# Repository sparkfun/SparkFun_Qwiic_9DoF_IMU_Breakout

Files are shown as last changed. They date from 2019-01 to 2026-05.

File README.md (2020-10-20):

SparkFun Qwiic 9DoF IMU  Breakout
========================================

SparkFun Qwiic 9DoF IMU Breakout

[*SparkFun Qwiic 9DoF IMU  Breakout (15335)*](https://www.sparkfun.com/products/15335)

The SparkFun 9DoF IMU Breakout incorporates all the amazing features of Invensense's ICM-20948 into a Qwiic-enabled breakout board complete with a logic shifter and broken out GPIO pins for all your motion sensing needs. The ICM-20948 itself is an extremely low powered, I2C and SPI enabled 9-axis motion tracking device that is ideally suited for smartphones, tablets, wearable sensors, and IoT applications. Utilizing our handy Qwiic system, no soldering is required to connect it to the rest of your system. However, we still have broken out 0.1"-spaced pins in case you prefer to use a breadboard.

In addition to the 3-Axis Gyroscope with four selectable ranges, 3-Axis Accelerometer, again with four selectable ranges, and 3-axis magnetometer with an FSR to ±4900µT, the ICM-20948 also includes a Digital Motion Processor that offloads the computation of motion sensing algorithms from the detectors, allowing optimal performance of the sensors. We've also broken out all the ICM-20948 pin functionality to GPIO and labeled them I2C on the front, SPI on the back for ease of identification.

Repository Contents
-------------------

* **/Documentation** - Data sheets, additional product information
* **/Hardware** - Eagle design files (.brd, .sch)
* **/Production** - Production panel files (.brd)

Documentation
--------------
* **[Arduino Library](https://github.com/sparkfun/SparkFun_ICM-20948_ArduinoLibrary)** - Arduino library for the SparkFun Qwiic 9DoF IMU  Breakout.
* **[Python Package](https://github.com/sparkfun/Qwiic_9DoF_IMU_ICM20948_Py)** - Python Package (Qwiic_Py) for the SparkFun Qwiic 9DoF IMU  Breakout.
* **[Hookup Guide](https://learn.sparkfun.com/tutorials/sparkfun-9dof-imu-icm-20948-breakout-hookup-guide)** - Basic hookup guide for the SparkFun 9DoF IMU Breakout.
* **[SparkFun Fritzing repo](https://github.com/sparkfun/Fritzing_Parts)** - Fritzing diagrams for SparkFun products.

License Information
-------------------

This product is _**open source**_! 

Please review the LICENSE.md file for license information. 

If you have any questions or concerns on licensing, please contact techsupport@sparkfun.com.

Distributed as-is; no warranty is given.

- Your friends at SparkFun.

_<COLLABORATION CREDIT>_

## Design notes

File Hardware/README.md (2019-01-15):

SparkFun <PRODUCT NAME> Design Files
=====================================

The .sch and .brd files hare are Eagle CAD schematic and PCB design files from SparkFun Electronics.
A freeware version of Eagle can be found [here](http://www.cadsoftusa.com/download-eagle/freeware/).

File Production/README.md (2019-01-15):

SparkFun <PRODUCT NAME> Production Files
=========================================

These are the production files SparkFun uses for printing PCBs.

License Information
-------------------
This product is open source! 

The hardware is released under [Creative Commons ShareAlike 4.0 International](https://creativecommons.org/licenses/by-sa/4.0/).

Please use, reuse, and modify these files as you see fit. Please maintain attribution to SparkFun Electronics and release anything derivative under the same license.

Distributed as-is; no warranty is given.

- Your friends at SparkFun.

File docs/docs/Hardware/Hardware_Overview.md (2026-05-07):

# Hardware Overview

We've put a lot of effort into making this the most useful and versatile breakout for the ICM 20948. Let's take a closer look at all the special parts.

### Sensor

At the heart of the board (metaphorically and geometrically) is the ICM 20948 from Invensense. This puppy packs the ability to measure up to 10 unique values (3 axes of acceleration, rotational rate, and magnetic strength data as well as an on-board temperature sensor). The sensor is placed dead-center between the four 4-40 stand-off mounting holes to drastically simplify computation in dynamics. 

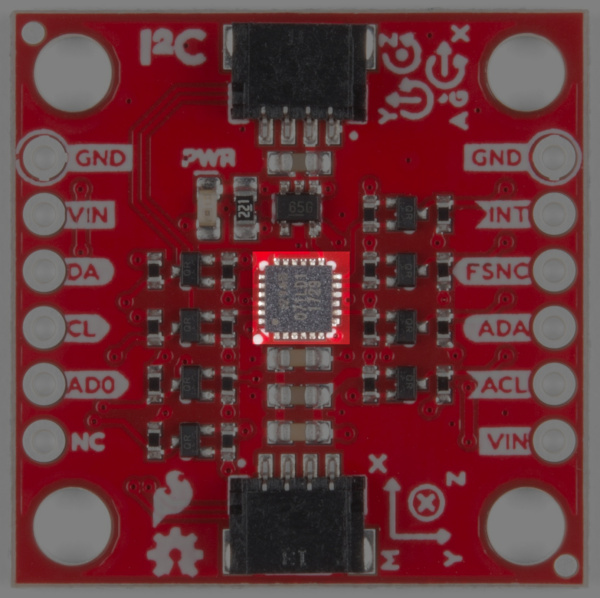
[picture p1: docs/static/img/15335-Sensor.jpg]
ICM20948 Sensor
[]

### Level Shifters

The ICM is a fickle fellow - optionally allowing a <b>3.3V</b> supply voltage but requiring I/O to work at 1.8V. This is just the price we pay for amazing technolojay (hey that rhymes). Since there aren't many popular development boards that run at the [voltage of the future](https://en.wikipedia.org/wiki/LVCMOS) we've added high speed level shifting to each and every IO pin. These cool MOSFETS allow for bi-directional voltage translation up to the maximum SPI speed of the ICM - 7MHz - which will allow you to make inertial measurements with fantastic temporal resolution. Feel free to use the ICM IO anywhere from 1.8V to 5.5V!

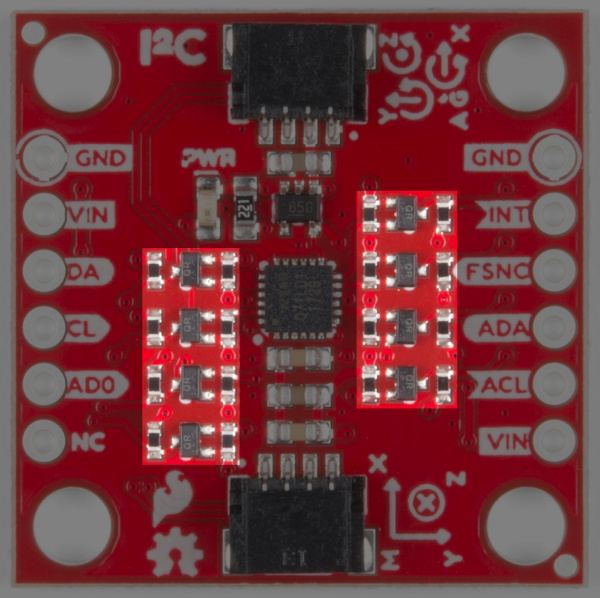
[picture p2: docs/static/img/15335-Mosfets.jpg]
Mosfets
[]

### Power

Input power on this board should be between **1.8-5.5V**. The ICM is riding the wave of 1.8V level devices so we've included a built-in regulator to make it easy to interface with 3.3V or 5V microcontrollers. There is an LED on the front of the board that will light up when the board is powered correctly. You can disable the LED functionality by cutting the LED jumper on the back of the board. This is described in the **_Jumpers_** section below. 

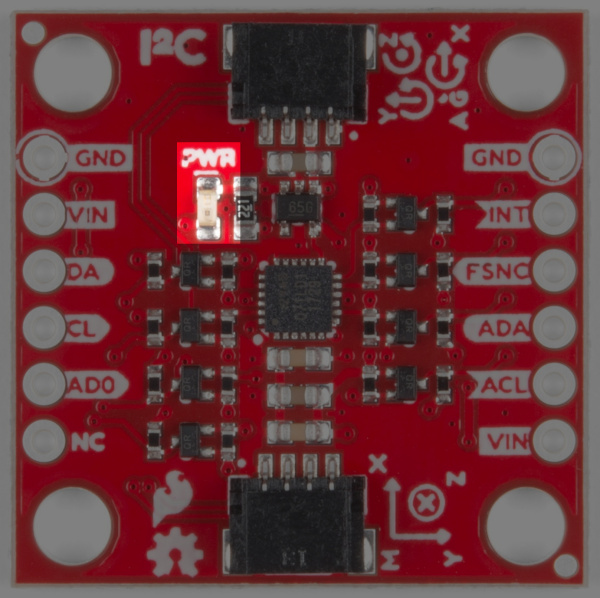
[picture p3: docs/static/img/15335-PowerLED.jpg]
Power LED
[]

### Qwiic Connectors

There are two Qwiic connectors on the board such that you can daisy-chain the boards should you choose to do so. If you're unfamiliar with our Qwiic system, head on over to our [Qwiic page](https://www.sparkfun.com/qwiic) to see the advantages! Of course, if you don't want to use Qwiic we've still broken out every pin on 0.1" spaced plated through-hole headers. You can find more information about these connections in the **_Headers_** section.

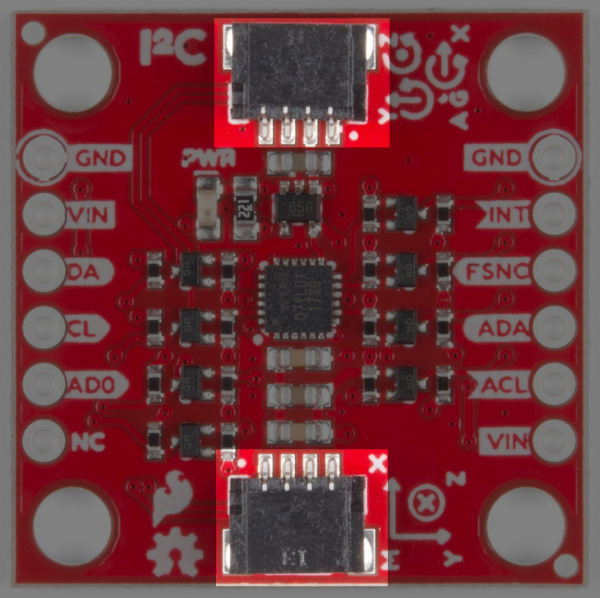
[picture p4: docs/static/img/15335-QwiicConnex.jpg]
Qwiic Connectors
[]

### GPIO

For flexibility, we've broken out functional pins for both I<sup>2</sup>C and SPI. There are no modifications required to switch between I<sup>2</sup>C mode and SPI out of the box, but if the 'ADR' jumper on the back is closed SPI will be unavailable.

| | |
| --- | --- |
| (https://cdn.sparkfun.com/r/600-600/assets/learn_tutorials/8/9/3/15335-GPIO_I2C.jpg) | (https://cdn.sparkfun.com/r/600-600/assets/learn_tutorials/8/9/3/15335-GPIO_SPI.jpg) |
| _I2C Pin Labels_ | _SPI Pin Labels_ |

### Jumpers

Look at all those jumpers on the back of the board! Here's what they do:  

#### Pullup Jumpers

* **I<sup>2</sup>C Pullup** - Does nothing, the pullups are not populated on the board because the TXS0108 has them built-in
* **Aux Pullup** - Cut these jumpers to disconnect the pullup resistors from the auxiliary I<sup>2</sup>C bus  

#### LED Jumper

* Cutting this jumper allows you to disable the LED functionality on the front of the board. 

#### Address Jumper

* When open (default) the address of the ICM is 0x69 and it is possible to use SPI communication. When soldered closed the address changes to 0x68. Closing the jumper prevents you from using SPI.

| | | |
| --- | --- | --- |
| (https://cdn.sparkfun.com/r/600-600/assets/learn_tutorials/8/9/3/15335-PullupJumpers.jpg) | (https://cdn.sparkfun.com/r/600-600/assets/learn_tutorials/8/9/3/15335-LEDJumper.jpg) | (https://cdn.sparkfun.com/r/600-600/assets/learn_tutorials/8/9/3/15335-AddrJumper.jpg) |
| _Pullup Jumpers_ | _LED Jumper_ | _I2C Address Jumper_ |

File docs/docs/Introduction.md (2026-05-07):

The [SparkFun 9DoF IMU Breakout](https://www.sparkfun.com/products/15335) incorporates all the amazing features of Invensense's ICM-20948 into a Qwiic-enabled breakout board replete with logic shifting and broken out GPIO pins for all your motion sensing needs. The ICM-20948 itself is an extremely low powered, I<sup>2</sup>C and SPI enabled 9-axis motion tracking device that is ideally suited for smartphones, tablets, wearable sensors, and IoT applications. Featuring a 3-Axis Gyroscope with four selectable ranges, a 3-Axis Accelerometer, again with four selectable ranges, a 3-axis compass with a wide range to  ±4900 µT, and an on-board Digital Motion Processor, this little breakout can even detect the motion of invisibility cloaks. Not really. Just checking to see if you were still with me. But it _is_ pretty amazing.

In this hookup guide, we'll connect our sensor up to our [Esp32 Thing Plus](https://www.sparkfun.com/products/14689) microcontroller and run a of quick (Qwiic) example to get you up and running with this fantastic board! 

### Required Materials

To follow along with this tutorial, you will need the 9DoF IMU Breakout with the following materials:

* [SparkFun Thing Plus - ESP32 WROOM](https://www.sparkfun.com/sparkfun-thing-plus-esp32-wroom-micro-b.html)
* [Qwiic Cable](https://www.sparkfun.com/flexible-qwiic-cable-100mm.html)
* [USB Micro-B Cable](https://www.sparkfun.com/reversible-usb-a-to-reversible-micro-b-cable-0-3m.html)

### Tools

If you choose to utilize the broken out GPIO, you will need a soldering iron, solder, and [general soldering accessories](https://www.sparkfun.com/categories/49).

* [Soldering Iron - 60W (Adjustable Temperature)](https://www.sparkfun.com/soldering-iron-60w-adjustable-temperature.html)
* [Solder Lead Free - 15-gram Tube](https://www.sparkfun.com/solder-lead-free-15-gram-tube.html)

### Suggested Reading

If you aren't familiar with the Qwiic system, we recommend reading [here for an overview](https://www.sparkfun.com/qwiic).

We would also recommend taking a look at the following tutorials if you aren't familiar with them:

* [How to Solder: Through-Hole Soldering](https://learn.sparkfun.com/tutorials/how-to-solder-through-hole-soldering)
* [Accelerometer Basics](https://learn.sparkfun.com/tutorials/accelerometer-basics)
* [I2C](https://learn.sparkfun.com/tutorials/i2c)
* [Serial Terminal Basics](https://learn.sparkfun.com/tutorials/terminal-basics)

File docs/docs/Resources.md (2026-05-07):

For more information on the ICM-20948, check out the links below: 

* [Schematic (PDF)](https://cdn.sparkfun.com/assets/c/7/8/f/8/15335_9DoF_Schematic.pdf)
* [Eagle Files(ZIP)](https://cdn.sparkfun.com/assets/e/3/8/8/4/15335_9DoF_IMU_EagleFiles.zip)
* [ICM-20948 Datasheet](https://cdn.sparkfun.com/assets/learn_tutorials/8/9/3/DS-000189-ICM-20948-v1.3.pdf)
* [ICM-20948 Arduino Library GitHub](https://github.com/sparkfun/SparkFun_ICM-20948_ArduinoLibrary)
* [Qwiic_9DoF_IMU_ICM20948_Py Python Module](https://github.com/sparkfun/Qwiic_9DoF_IMU_ICM20948_Py)
    * [ReadTheDocs](https://qwiic-9dof-imu-icm20948-py.readthedocs.io/en/latest/?)
* [9DoF IMU GitHub](https://github.com/sparkfun/SparkFun_Qwiic_9DoF_IMU_Breakout)

This tutorial focuses on using the 9DoF with Arduino. To use the ICM-20948 on a Raspberry Pi with Python, check out the [Qwiic SHIM Kit Hookup Guide for Raspberry Pi](https://learn.sparkfun.com/tutorials/qwiic-shim-kit-hookup-guide-for-raspberry-pi) for more information.

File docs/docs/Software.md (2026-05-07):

In this example, we are using the [SparkFun Esp32 Thing WROOM Plus](https://www.sparkfun.com/products/14689). If you have not used this board before, head on over to the [ESP32 Thing Plus Hookup Guide](https://learn.sparkfun.com/tutorials/esp32-thing-plus-hookup-guide) for a general overview, as well as information on getting set up with board definitions.

In order to use the ICM-20948 breakout, you'll need to install the [SparkFun ICM-20948 Arduino Library](https://github.com/sparkfun/SparkFun_ICM-20948_ArduinoLibrary).  We recommend you install the library via the Arduino IDE by using the library manager and search for **Sparkfun 9DoF IMU Breakout**. Users who want to manually install the library can download it from the the [GitHub repo](https://github.com/sparkfun/SparkFun_ICM-20948_ArduinoLibrary).

### Example 1

In this example, we've hookup up our ICM-20948 to an [ESP32 Thing Plus](https://www.sparkfun.com/products/14689) using a short [Qwiic cable](https://www.sparkfun.com/products/14427). 

Once you've installed the ICM-20948 library, load the first example sketch from **File**->**Examples**->**SparkFun 9DoF IMU Breakout - ICM 20948 - Arduino Library**->**Arduino**->**Example1_Basics**. 

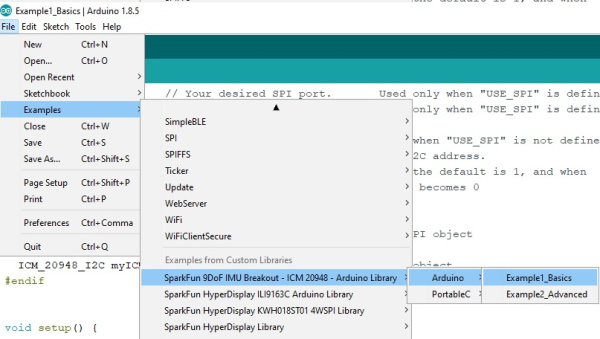
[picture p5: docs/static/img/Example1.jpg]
Where to find Example 1 in Arduino
[]

The very first thing you'll see in the code is the `#include` statement for the library. Alongside that is a convenient link that will help you get the library through the Arduino library manager. Next is a commented out `#define` statement called 'USE_SPI'. If instead you have chosen to connect your ICM with the SPI pins all you need to do is uncomment that line.

``` c
    #include "ICM_20948.h"  // Click here to get the library: http://librarymanager/All#SparkFun_ICM_20948_IMU
    
    //#define USE_SPI       // Uncomment this to use SPI
```    

Up next is a short section where you can configure your particular setup. First of all if you need to change your serial port, e.g. if you're using a SAMD21 board, you can change the 'SERIAL_PORT' define ('SerialUSB' for SAMD21). You can do the same to change your I2C port or SPI port, depending on which you're using. When using I2C you have the ability to change the I2C address of the sensor with the Address 0 bit. By default it is '1' but you could change it to 0 if you've closed the 'ADR' jumper. When using SPI you need to specify a chip select pin - in the example we default to pin 2.

``` c
    #define SERIAL_PORT Serial
    
    #define SPI_PORT SPI    // Your desired SPI port.       Used only when "USE_SPI" is defined
    #define CS_PIN 2        // Which pin you connect CS to. Used only when "USE_SPI" is defined
    
    #define WIRE_PORT Wire  // Your desired Wire port.      Used when "USE_SPI" is not defined
    #define AD0_VAL   1     // The value of the last bit of the I2C address. 
                            // On the SparkFun 9DoF IMU breakout the default is 1, and when 
                            // the ADR jumper is closed the value becomes 0
```

That's it for stuff you (might) need to do to set up the example! Now we'll just all hop in the bus, take a tour, and I'll point out items on your right and left.

The next little block creates either a `ICM_20948_I2C` or `ICM_20948_SPI` object called 'myICM'. Since they have the same name, and they both inherit from the grandaddy `ICM_20948` class, we'll be able to use them interchangeably later on in the example.

``` c
    #ifdef USE_SPI
      ICM_20948_SPI myICM;  // If using SPI create an ICM_20948_SPI object
    #else
      ICM_20948_I2C myICM;  // Otherwise create an ICM_20948_I2C object
    #endif
```

In the `setup()` function we have your standard Arduino initialization of your serial port, and then we have the last interface-dependent section. There you'll see the 'myICM' object being started up with the appropriate arguments for the chosen interface. This example shows all arguments being explicitly stated, but it is also possible to call the `.begin()` function with default arguments. The initialization will repeat with a delay until the device is successfully found. If it is not connecting try checking your wiring.

``` c
    #ifdef USE_SPI
        SPI_PORT.begin();
        myICM.begin( CS_PIN, SPI_PORT ); 
    #else
        WIRE_PORT.begin();
        WIRE_PORT.setClock(400000);
        myICM.begin( WIRE_PORT, AD0_VAL );
    #endif
```

Here's a little trick for debugging the ICM - nearly all operations will update the internal 'myICM.status' value. You can check it directly (0 means all good, anything else is an error) or you can use the `statusString()` method to get the latest status in human-readable form.

``` c
        SERIAL_PORT.print( F("Initialization of the sensor returned: ") );
        SERIAL_PORT.println( myICM.statusString() );
        if( myICM.status != ICM_20948_Stat_Ok ){
          SERIAL_PORT.println( "Trying again..." );
          delay(500);
        }else{
          initialized = true;
        }
```

The last part of the sketch is the `loop()` where the sensor gets polled for new data, and that data gets pushed over the serial port. All the data is contained in the 'AGMT' structure, which stands for Accelerometer, Gyroscope, Magnetometer, and Temperature sensors. For convenience this sketch also includes functions (that are not part of the library) to print the results in a pretty format. 

``` c
    void loop() {
    
      if( myICM.dataReady() ){
        myICM.getAGMT();                // The values are only updated when you call 'getAGMT'
    //    printRawAGMT( myICM.agmt );     // Uncomment this to see the raw values, taken directly from the agmt structure
        printScaledAGMT( myICM.agmt);   // This function takes into account the sclae settings from when the measurement was made to calculate the values with units
        delay(30);
      }else{
        Serial.println("Waiting for data");
        delay(500);
      }
      
    }
```
    
When you open up your [Serial Monitor](https://learn.sparkfun.com/tutorials/terminal-basics), you should see something like the following: 

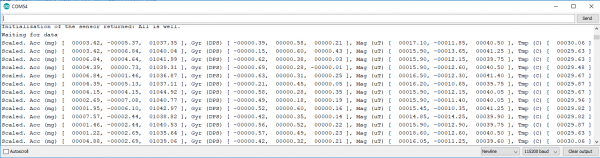
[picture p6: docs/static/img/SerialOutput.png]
Serial Output
[]

There ya have it! Now go ahead and hack it up.

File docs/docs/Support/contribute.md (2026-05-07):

# Contribute

## Improve our Documentation

All of this documentation can be modified by you! Please help us make it better.

* These pages are contained in the [`docs` folder of the SparkFun Qwiic 9DoF IMU Breakout repository](https://github.com/sparkfun/SparkFun_Qwiic_9DoF_IMU_Breakout/tree/main/docs).

### Submit a Correction

1. Fork this repo
2. Add your corrections or improvements to the markdown file
3. File a pull request with your changes, and enjoy making the ~~words~~ ~~worlds~~ world a better place.
    * Once received, the documentation specialist will automatically be notified.
    * We will review your suggested improvements to make sure they are correct and fit within our documentation standards.

## Improve our Hardware Design

This hardware design is open-source! Please help us make it better.

* Our board design files are contained in the [`Hardware` folder of the SparkFun Qwiic 9DoF IMU Breakout repository](https://github.com/sparkfun/SparkFun_Qwiic_9DoF_IMU_Breakout_IoT_9DoF/tree/main/Hardware).

### Submit a Design Improvement

1. Fork this repo
2. Add your design improvements
3. File a pull request with your changes, and enjoy making the ~~words~~ ~~worlds~~ world a better place.
    * Once received, the engineer in charge of the original design will automatically be notified.
    * We will review your suggested improvements, if they are within our board design standards and meet our product design requirements, we will flag these changes for our next board revision. *(Please note, that even if your suggestion is accepted, these changes may not be immediate. We may have to cycle through our current product inventory first.)*

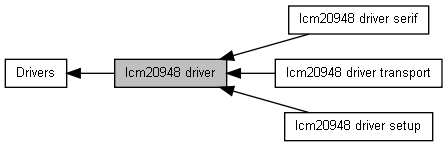
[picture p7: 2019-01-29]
Documentation/eMD/1.0.0/doc/libIDD/html/a00122.png

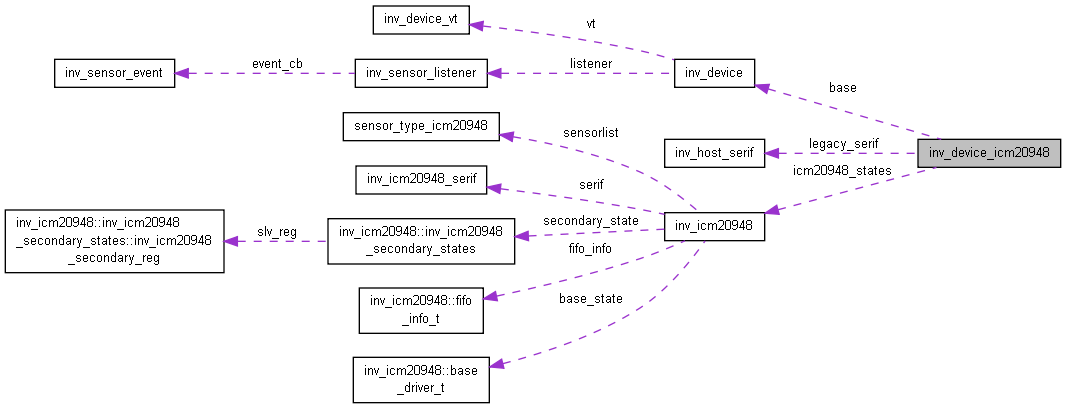
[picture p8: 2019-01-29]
Documentation/eMD/1.0.0/doc/libIDD/html/a00148.png

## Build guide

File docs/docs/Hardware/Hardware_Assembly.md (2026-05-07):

# Hardware Assembly

One of the many advantages of the Qwiic system is that hooking up your hardware is extremely simple. Simply grab a Qwiic cable and plug your 9DoF in! 

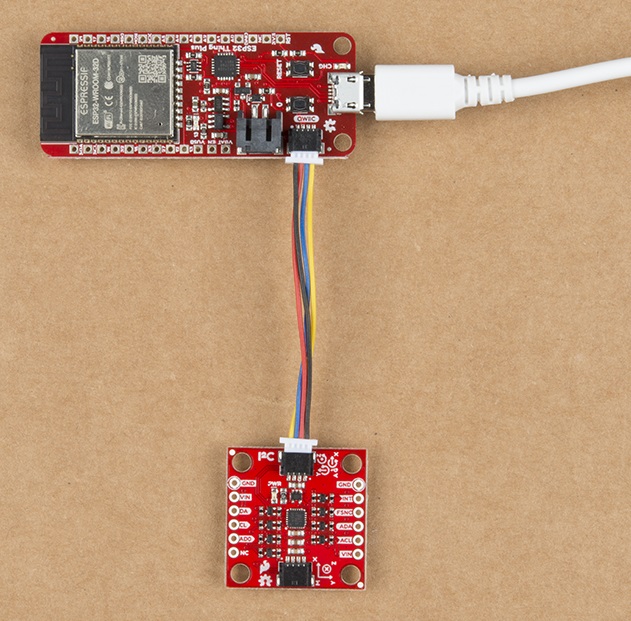
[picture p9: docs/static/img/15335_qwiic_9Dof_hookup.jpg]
Connecting the 9DoF Breakout to a microcontroller via Qwiic cable
[]

<div class="alert alert-danger" role="alert"><b>&#x26A1;WARNING!</b> <br />If you are using the ESP32 Thing Plus, make sure your power supply is <b>5V</b>, NOT 5.1V. We have noticed a power spike in our <a href="https://www.sparkfun.com/products/13831"> 5.1V power supplies</a>, that can damage the IC on the ESP32 Thing Plus. Long cables can also generate a large enough voltage spike to damage the IC. We recommend keeping power supply cables shorter than 6 feet to minimize potential damage.</div>

If you'd like to use the broken out GPIO pins, things get a bit more complicated. That said, to make life a little easier we've organized them by function, and provided lots of labels. You'll first notice that one side has the text 'I<sup>2</sup>C' and the other side says 'SPI.' The labels on either side are those that apply to that kind of communication. 

| | |
| --- | --- |
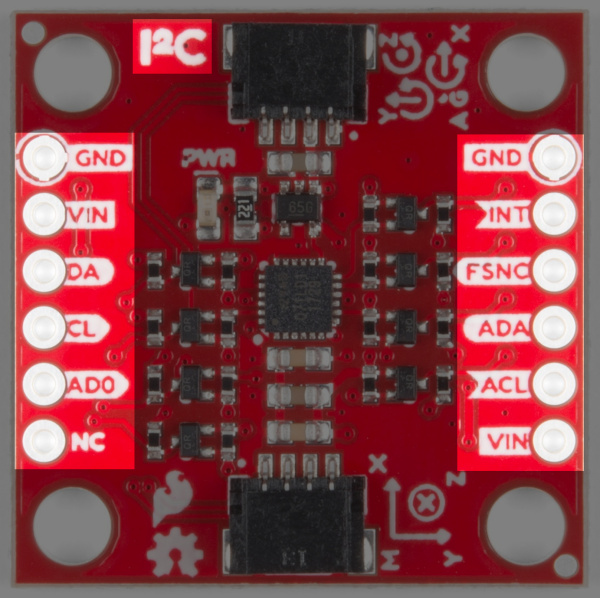
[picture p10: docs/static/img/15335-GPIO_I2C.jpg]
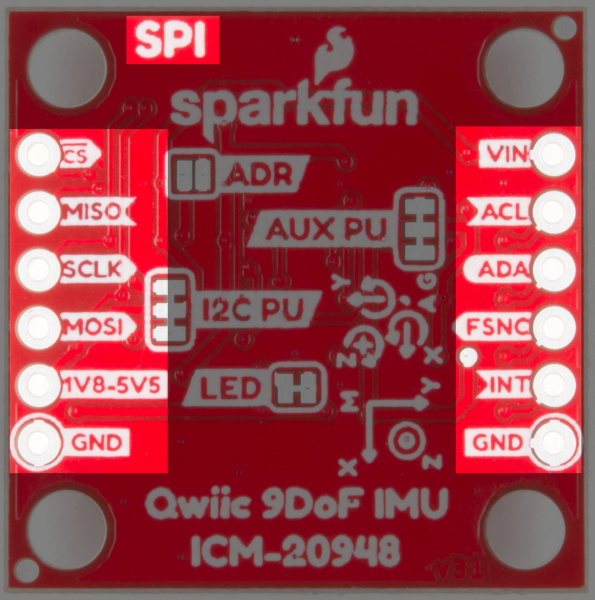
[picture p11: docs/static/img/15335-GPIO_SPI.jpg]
|  |  |
| _I2C Pin Labels_ | _SPI Pin Labels_ |

Next, you'll see that on the left side are the main connections to the host microcontroller. When connecting I<sup>2</sup>C you'll have a 'No Connect' pin that serves as the chip select when using SPI. As noted before, there are no modifications required to switch between I<sup>2</sup>C mode and SPI out of the box. However if the 'ADR' jumper is closed SPI will be unavailable.

On the right side are connections to external sensors that can be controlled by the ICM, as well as the 'INT' and 'FSYNC' interrupt pins. The auxiliary I<sup>2</sup>C bus pins are level shifted to/from the 'VIN' level that you supply. 

| Breakout Board Pin Functions (SPI) | | | |
| --- | --- | --- | --- |
| Breakout Pin | Arduino Uno | Esp32 Thing Plus | Microcontroller Pin Requirements |
| MOSI | 11  | 18  | Data output of chosen SPI port |
| SCLK | 13  | 5 | Clock output of chosen SPI port |
| MISO | 12  | 19  | Data input of chosen SPI port |
| CS  | 2 | 2 | An output pin to select the ICM for SPI |

| Breakout Board Pin Functions (I2C) | | | |
| --- | --- | --- | --- |
| Breakout Pin | Arduino Uno | Esp32 Thing Plus | Microcontroller Pin Requirements |
| DA  | SDA | 23  | Data line of chosen I2C port |
| CL  | SCL | 22  | Clock line of chosen I2C port |
| AD0 | \-  | \-  | Optional - use to control I2C address from software |

| Breakout Board Pin Functions (Auxiliary I2C and Interrupts) | | | |
| --- | --- | --- | --- |
| Breakout Pin | Arduino Uno | Esp32 Thing Plus | Microcontroller Pin Requirements |
| ADA | \-  | \-  | Data line of auxiliary I2C bus |
| ACL | \-  | \-  | Clock line of auxiliary I2C bus |
| FSYNC | \-  | \-  | Optional - synchronize measurements with a signal out from the microcontroller |
| INT | \-  | \-  | Optional - respond to configurable interrupts in from the ICM |

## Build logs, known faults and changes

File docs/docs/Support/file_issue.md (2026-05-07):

# Submit Issues

## Support

If you need technical assistance and more information on a product that is not working as you expected, visit the [SparkFun Community](https://community.sparkfun.com). The community forums are monitored by the SparkFun Technical Support Team and the SparkFun community as a whole.

## Existing Issue

Spot something wrong? Please check the list of reported and fixed issues  .  in this repository.

## Discrepancies in the Documentation

All of this documentation can be modified by you! Please help us make it better.

* The documentation files for these pages are contained in the [`docs` folder of the SparkFun Qwiic 9DoF IMU Breakout repository](https://github.com/sparkfun/SparkFun_Qwiic_9DoF_IMU_Breakout/tree/main/docs).

### Spot something wrong?

If a section of the documentation is incorrect, please [open an issue](https://github.com/sparkfun/SparkFun_Qwiic_9DoF_IMU_Breakout/issues) and let us know.

### Do you have a suggested correction?

1. With a GitHub account, fork this repo
2. Add your correction(s) or improvement(s) to the markdown file(s)
3. File a pull request with your changes, and enjoy making the ~~words~~ ~~worlds~~ world a better place.
    * Once received, the documentation specialist will automatically be notified.
    * We will review your suggested improvement(s) to make sure they are correct and fit within our documentation standards.

## Problems in the Hardware Design

All of our designs are open-source! Please help us make it better.

* Our board design files are contained in the [`Hardware` folder of the SparkFun Qwiic 9DoF IMU Breakout repository](https://github.com/sparkfun/SparkFun_Qwiic_9DoF_IMU_Breakout/tree/main/Hardware).

### Does something not make sense?

If part of the design is confusing, please [open an issue](https://github.com/sparkfun/SparkFun_Qwiic_9DoF_IMU_Breakout/issues) and let us know.

### Did we forget to include an important function of the board?

Please keep in mind that we may intentionally exclude certain functions of the board to meet our product design requirements.

If part of the board's functionality is missing, please [open an issue](https://github.com/sparkfun/SparkFun_Qwiic_9DoF_IMU_Breakout/issues) and file a feature request.

### Do you wish to contribute directly to improving the board design?

1. With a GitHub account, Fork this repo
2. Add your design improvement(s)
3. File a pull request with your changes, and enjoy making the ~~words~~ ~~worlds~~ world a better place.
    * Once received, the engineer in charge of the original design will automatically be notified.
    * We will review your suggested improvement(s), if they are within our board design standards and meet our product design requirements, we will flag these changes for our next board revision. *(Please note, that even if your suggestion is accepted, these changes may not be immediate. We may have to cycle through our current product inventory first.)*

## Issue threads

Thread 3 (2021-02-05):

Level Shifting MOSFET and Power Regulator

iharshadec, 2021-02-05:
Looks Like my board is damaged as it's not generating Power.
What is the regulator and mosfet used in this design?

PaulZC, 2021-02-15:
Hi @iharshadec ,
Apologies for the delay. From the Eagle files: the regulator is a SP6214-1.8V; the FET is RE1C002UN.
Best wishes,
Paul

iharshadec, 2021-02-16:
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

Thank you Paul,
I will order this regulator first and replace to see if I get the board working back.

Closed 2021-02-15.

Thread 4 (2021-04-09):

Low-power mode: Extremely high power consumption

adamgarbo, 2021-04-09:
Hi folks,

I've been meaning to follow up on a GitHub issue I previously raised regarding the ICM-20948's high power consumption: (https://github.com/sparkfun/SparkFun_ICM-20948_ArduinoLibrary/issues/21). It appears that the level shifting circuitry on the ICM-20948 is causing an extremely high current draw of 3.4 mA when placed in low power mode that cannot be disabled.

When in Full-Chip Sleep Mode the ICM-20948 should be able to achieve a quiescent draw of 8 uA. As the ICM-20948 is now the "go-to" IMU, I believe it would be a worthwhile effort to address this power consumption issue when time permits.

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

Cheers,
Adam

adamgarbo, 2022-03-10:
Closing as unresolved. High power consumption is a known issue for the ICM-20948.

Closed 2022-03-10.

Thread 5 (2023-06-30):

How to get this sensor working on lineage OS?

anivader1789, 2023-06-30:
We have this IMU sensor and we have a rasberry pi 4 Model B. Installed Lineage OS on it (https://konstakang.com/devices/rpi4/LineageOS20/). We want to install drivers for this sensor to work with our setup. Any help appreciated.

PaulZC, 2023-07-01:
Hi @anivader1789 ,

Please see: https://github.com/sparkfun/Qwiic_9DoF_IMU_ICM20948_Py

Best wishes,
Paul

Closed 2023-07-01.

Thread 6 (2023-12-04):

Wrong values for accelerometer configuration

ezono-Muhammad, 2023-12-04:
### Subject of the issue
Wrong values for accelerometer configuration

### Your workbench
* Raspberry pi 4
* I2C. IMU address is 0x68
* Via i2c connection on Raspberry pi 4

### Steps to reproduce
Using the following code :

```
from __future__ import print_function
import qwiic_icm20948
import time
import sys

if __name__ == "__main__":

    IMU = qwiic_icm20948.QwiicIcm20948(address=0x68)
    IMU.setBank(2)
    IMU._i2c.writeByte(IMU.address, IMU.AGB2_REG_ACCEL_CONFIG_1, 0x23)
    register = IMU._i2c.readByte(IMU.address, IMU.AGB2_REG_ACCEL_CONFIG_1)
    print(register)
```

### Expected behaviour
The return value should be 0x23

### Actual behaviour
The return value is 0x01

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

Closed 2023-12-04.

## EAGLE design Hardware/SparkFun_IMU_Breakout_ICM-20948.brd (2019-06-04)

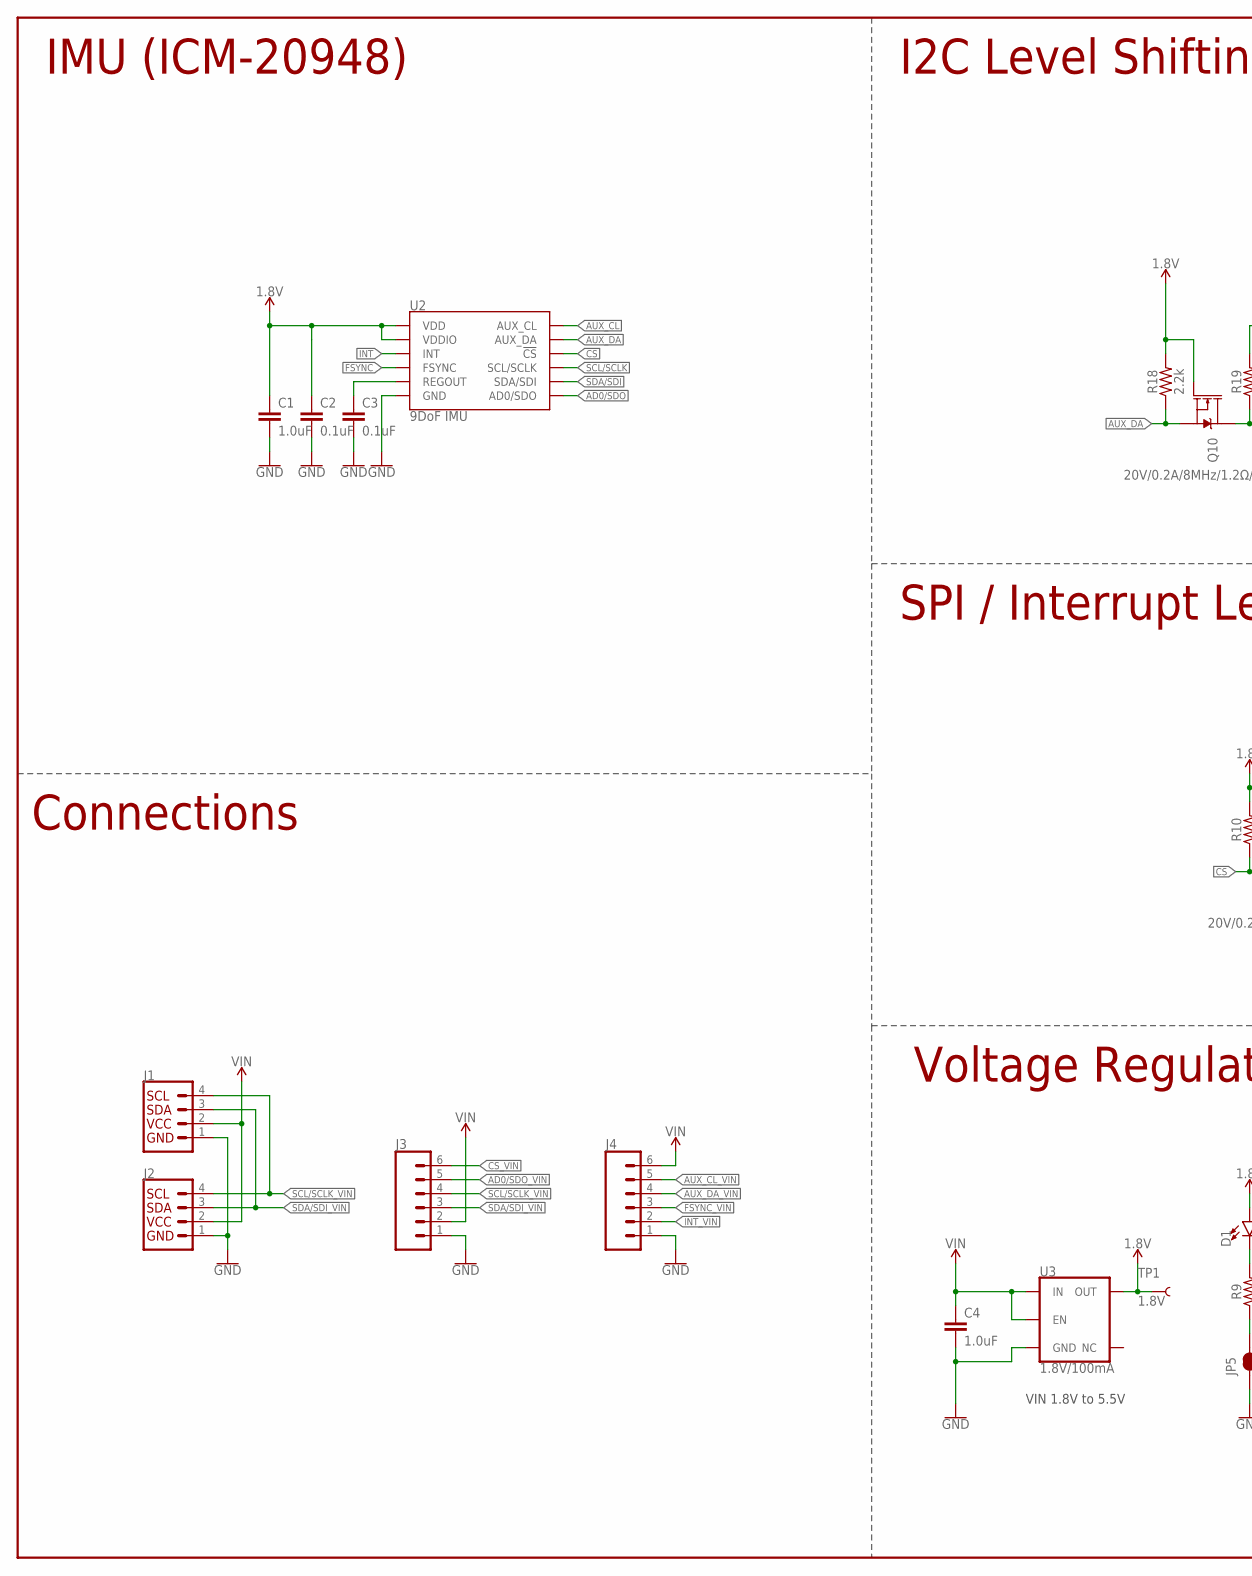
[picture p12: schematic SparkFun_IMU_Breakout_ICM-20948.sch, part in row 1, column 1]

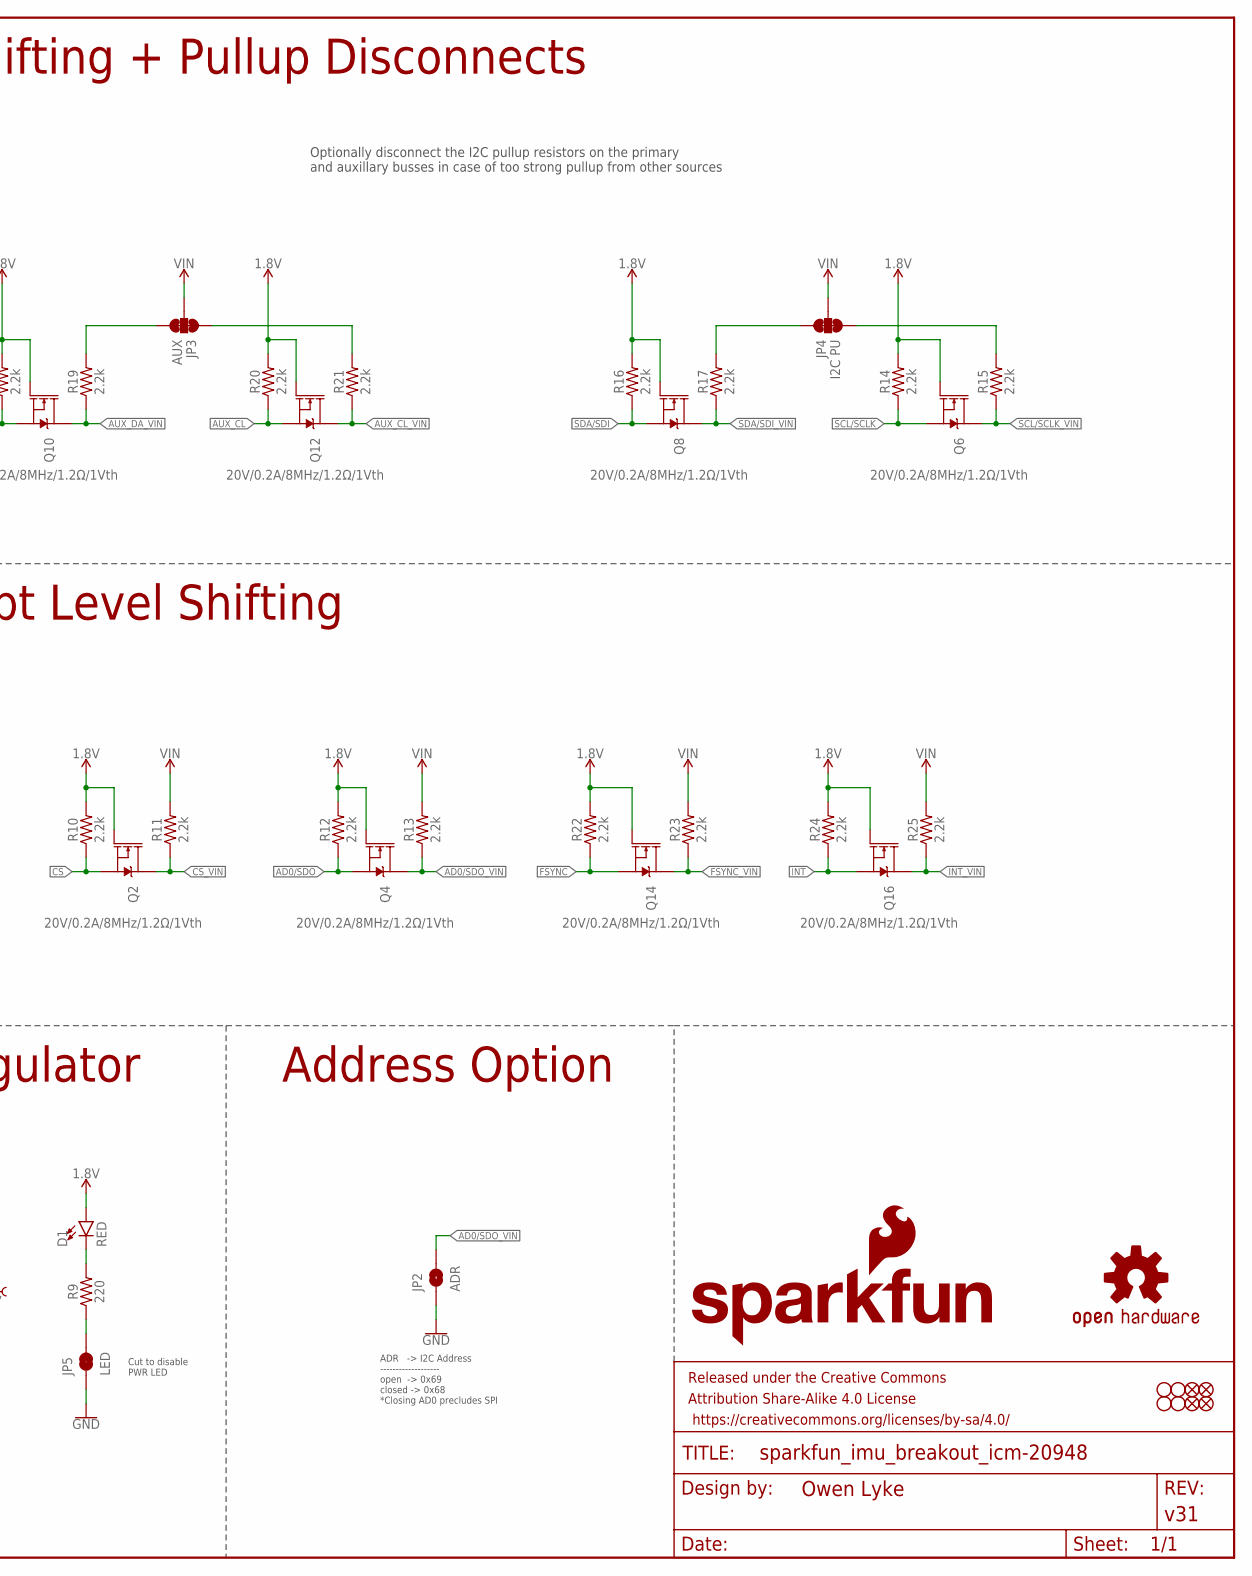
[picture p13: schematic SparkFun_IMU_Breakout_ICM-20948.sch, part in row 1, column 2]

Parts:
C1, C4: 1.0uF; 0603
C2, C3: 0.1uF; 0603
D1: RED; LED-0603
FD1, FD2, FD3, FD4: FIDUCIAL1X2; FIDUCIAL-1X2
FRAME2: FRAME-LEDGER; CREATIVE_COMMONS
H1, H2, H3, H4: STAND-OFF
J1, J2: QWIIC_CONNECTORJS-1MM; JST04_1MM_RA
J3, J4: CONN_06NO_SILK_NO_POP; 1X06_NO_SILK
JP2: ADR; SMT-JUMPER_2_NO_SILK
JP3: AUX; SMT-JUMPER_3_2-NC_TRACE_SILK
JP4: I2C PU; SMT-JUMPER_3_2-NC_TRACE_SILK
JP5: LED; SMT-JUMPER_2_NC_TRACE_SILK
LOGO1: SFE_LOGO_NAME_FLAME.1_INCH; SFE_LOGO_NAME_FLAME_.1
LOGO2: OSHW-LOGOMINI; OSHW-LOGO-MINI
Q2, Q4, Q6, Q8, Q10, Q12, Q14, Q16: 20V/0.2A/8MHz/1.2Ω/1Vth; SOT-416FL
R9: 220; 0603
R10, R11, R12, R13, R14, R15, R16, R17, R18, R19, R20, R21, R22, R23, R24, R25: 2.2k; 0402-TIGHT
TP1: 1.8V; PAD.03X.03
U2: 9DoF IMU; QFN24-3X3
U3: 1.8V/100mA; SC70

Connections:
1.8V: C1.1, C2.1, D1.A, Q2.1 (G), Q4.1 (G), Q6.1 (G), Q8.1 (G), Q10.1 (G), Q12.1 (G), Q14.1 (G), Q16.1 (G), R10.2, R12.2, R14.2, R16.2, R18.2, R20.2, R22.2, R24.2, TP1.P$1, U2.8 (VDDIO), U2.13 (VDD), U3.5 (OUT)
!CS: Q2.2 (S), R10.1, U2.22 (!CS)
!CS!_VIN: J3.6, Q2.3 (D), R11.1
AD0/SDO: Q4.2 (S), R12.1, U2.9 (AD0/SDO)
AD0/SDO_VIN: J3.5, JP2.2, Q4.3 (D), R13.1
AUX_CL: Q12.2 (S), R20.1, U2.7 (AUX_CL)
AUX_CL_VIN: J4.5, Q12.3 (D), R21.1
AUX_DA: Q10.2 (S), R18.1, U2.21 (AUX_DA)
AUX_DA_VIN: J4.4, Q10.3 (D), R19.1
FSYNC: Q14.2 (S), R22.1, U2.11 (FSYNC)
FSYNC_VIN: J4.3, Q14.3 (D), R23.1
GND: C1.2, C2.2, C3.2, C4.2, J1.1, J2.1, J3.1, J4.1, JP2.1, JP5.1, U2.18 (GND), U2.20 (GND), U3.2 (GND)
INT: Q16.2 (S), R24.1, U2.12 (INT)
INT_VIN: J4.2, Q16.3 (D), R25.1
unnamed: C3.1, U2.10 (REGOUT)
unnamed: JP4.3, R15.2
unnamed: JP4.1, R17.2
unnamed: JP3.1, R21.2
unnamed: JP3.3, R19.2
unnamed: D1.C, R9.2
unnamed: JP5.2, R9.1
SCL/SCLK: Q6.2 (S), R14.1, U2.23 (SCL/SCLK)
SCL/SCLK_VIN: J1.4, J2.4, J3.4, Q6.3 (D), R15.1
SDA/SDI: Q8.2 (S), R16.1, U2.24 (SDA/SDI)
SDA/SDI_VIN: J1.3, J2.3, J3.3, Q8.3 (D), R17.1
VIN: C4.1, J1.2, J2.2, J3.2, J4.6, JP3.2, JP4.2, R11.2, R13.2, R23.2, R25.2, U3.1 (IN), U3.3 (EN)

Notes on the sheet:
VIN 1.8V to 5.5V
IMU (ICM-20948)
I2C Level Shifting + Pullup Disconnects
Connections
Voltage Regulator
SPI / Interrupt Level Shifting
ADR -> I2C Address ------------------- open -> 0x69 closed -> 0x68 *Closing AD0 precludes SPI
Optionally disconnect the I2C pullup resistors on the primary and auxillary busses in case of too strong pullup from other sources
Cut to disable PWR LED
Address Option

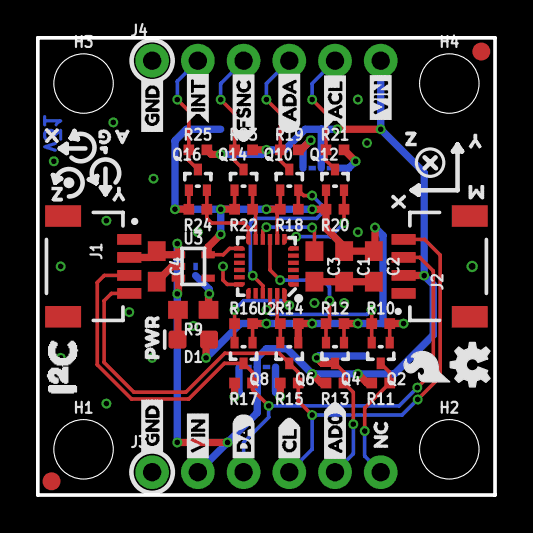
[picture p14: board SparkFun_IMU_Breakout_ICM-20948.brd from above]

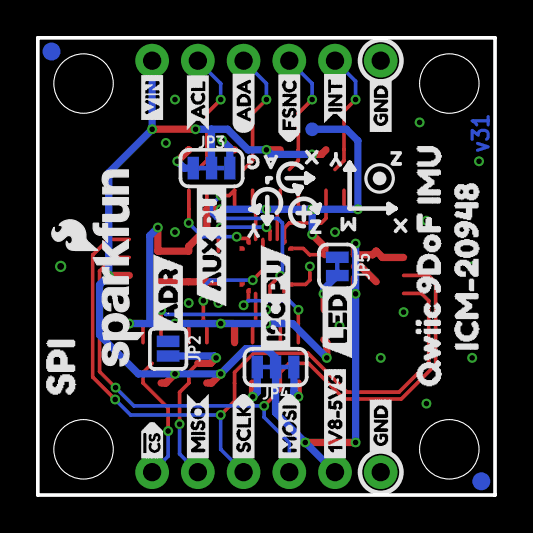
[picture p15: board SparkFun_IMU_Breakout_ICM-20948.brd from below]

Board: 2 copper layers, 25.4 x 25.4 mm, 104 parts (36 on the bottom side), 26 nets.

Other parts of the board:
U$1, U$2, U$22, U$24: GND4
U$3: PWR0
U$4, U$21: INT3
U$5, U$20: FSNC2
U$6, U$19: ACL1
U$7, U$18: ADA0
U$8: MISO13
U$9: MOSI14
U$10: SCLK15
U$11: #CS16
U$12: 1V8#5V57
U$13, U$30, U$44: VIN5
U$14: NC17
U$15: CL4
U$16: DA2
U$17: AD012
U$23: ADR2
U$25: I2C_PU21
U$26: SPI19
U$27: AUX_PU24
U$28: SFE_LOGO_FLAME_.1
U$29: LED23
U$31: ICM#2094820
U$34, U$40, U$50, U$57: X0
U$35, U$41, U$51, U$58: Y1
U$36, U$42, U$52, U$59: Z2
U$37, U$60: G5
U$38, U$61: A4
U$39, U$49: M3
U$43: QWIIC_9DOF_IMU_0
U$45: I#C1

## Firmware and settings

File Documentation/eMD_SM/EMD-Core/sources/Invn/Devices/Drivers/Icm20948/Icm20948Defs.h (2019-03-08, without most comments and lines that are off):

#define _INV_ICM20948_DEFINES_H_
#include <string.h>
#include <stdlib.h>
#include "Icm20948Dmp3Driver.h"
#ifdef __cplusplus
extern "C" {
#endif
#define HW_AK8963 0x20
#define HW_AK8975 0x21
#define HW_AK8972 0x22
#define HW_AK09911 0x23
#define HW_AK09912 0x24
#define HW_AK09916 0x25
#define HW_ICM20648 0x01
#define HW_ICM20948 0x02
#define USE_ICM20948 1
#if defined USE_ICM20648
#define MEMS_CHIP  HW_ICM20648
#endif
#if defined USE_ICM20948
#define MEMS_CHIP  HW_ICM20948
#endif
#if !defined(MEMS_CHIP)
    #error "MEMS_CHIP is not defined"
#elif MEMS_CHIP != HW_ICM20648 \
        && MEMS_CHIP != HW_ICM20948
    #error "Unknown value for MEMS_CHIP"
#endif
#define DMP_LOAD_START 0x90
#define MPU_SUCCESS (0)
#define MPU_COMPASS_NOT_FOUND (int)0x00ABCDEF
#define MSEC_PER_SEC 1000
#define NSEC_PER_MSEC 1000000
#define NSEC_PER_SEC NSEC_PER_MSEC * MSEC_PER_SEC
#define FIFO_DIVIDER 19
#define REG_BANK_0 0x00
#define REG_BANK_1 0x01
#define DIAMOND_I2C_ADDRESS     0x68
#define BANK_0                  (0 << 7)
#define BANK_1                  (1 << 7)
#define BANK_2                  (2 << 7)
#define BANK_3                  (3 << 7)
#define REG_WHO_AM_I            (BANK_0 | 0x00)
#define REG_LPF                 (BANK_0 | 0x01)
#define REG_USER_CTRL           (BANK_0 | 0x03)
#define BIT_DMP_EN                      0x80
#define BIT_FIFO_EN                     0x40
#define BIT_I2C_MST_EN                  0x20
#define BIT_I2C_IF_DIS                  0x10
#define BIT_DMP_RST                     0x08
#define BIT_DIAMOND_DMP_RST			    0x04
#define REG_LP_CONFIG           (BANK_0 | 0x05)
#define BIT_I2C_MST_CYCLE               0x40
#define BIT_ACCEL_CYCLE                 0x20
#define BIT_GYRO_CYCLE                  0x10
#define REG_PWR_MGMT_1          (BANK_0 | 0x06)
#define BIT_H_RESET                     0x80
#define BIT_SLEEP                       0x40
#define BIT_LP_EN                       0x20
#define BIT_CLK_PLL                     0x01
#define REG_PWR_MGMT_2          (BANK_0 | 0x07)
#define BIT_PWR_PRESSURE_STBY           0x40
#define BIT_PWR_ACCEL_STBY              0x38
#define BIT_PWR_GYRO_STBY               0x07
#define BIT_PWR_ALL_OFF                 0x7f
#define REG_INT_PIN_CFG         (BANK_0 | 0x0F)
#define BIT_INT_LATCH_EN                0x20
#define BIT_BYPASS_EN                   0x02
#define REG_INT_ENABLE          (BANK_0 | 0x10)
#define BIT_DMP_INT_EN                  0x02
#define REG_INT_ENABLE_1        (BANK_0 | 0x11)
#define BIT_DATA_RDY_3_EN               0x08
#define BIT_DATA_RDY_2_EN               0x04
#define BIT_DATA_RDY_1_EN               0x02
#define BIT_DATA_RDY_0_EN               0x01
#define REG_INT_ENABLE_2        (BANK_0 | 0x12)
#define BIT_FIFO_OVERFLOW_EN_0          0x1
#define REG_INT_ENABLE_3        (BANK_0 | 0x13)
#define REG_DMP_INT_STATUS      (BANK_0 | 0x18)
#define BIT_WAKE_ON_MOTION_INT          0x08
#define BIT_MSG_DMP_INT                 0x0002
#define BIT_MSG_DMP_INT_0               0x0100  // CI Command
#define BIT_MSG_DMP_INT_2               0x0200  // CIM Command - SMD
#define BIT_MSG_DMP_INT_3               0x0400  // CIM Command - Pedometer
#define BIT_MSG_DMP_INT_4               0x1000  // CIM Command - Pedometer binning
#define BIT_MSG_DMP_INT_5               0x2000  // CIM Command - Bring To See Gesture
#define BIT_MSG_DMP_INT_6               0x4000  // CIM Command - Look To See Gesture
#define REG_INT_STATUS          (BANK_0 | 0x19)
#define BIT_DMP_INT                     0x02
#define REG_INT_STATUS_1        (BANK_0 | 0x1A)
#define REG_INT_STATUS_2        (BANK_0 | 0x1B)
#define REG_SINGLE_FIFO_PRIORITY_SEL        (BANK_0 | 0x26)
#define REG_GYRO_XOUT_H_SH      (BANK_0 | 0x33)
#define REG_TEMPERATURE         (BANK_0 | 0x39)
#define REG_TEMP_CONFIG         (BANK_0 | 0x53)
#define REG_EXT_SLV_SENS_DATA_00 (BANK_0 | 0x3B)
#define REG_EXT_SLV_SENS_DATA_08 (BANK_0 | 0x43)
#define REG_EXT_SLV_SENS_DATA_09 (BANK_0 | 0x44)
#define REG_EXT_SLV_SENS_DATA_10 (BANK_0 | 0x45)
#define REG_FIFO_EN             (BANK_0 | 0x66)
#define BIT_SLV_0_FIFO_EN               0x01
#define REG_FIFO_EN_2           (BANK_0 | 0x67)
#define BIT_PRS_FIFO_EN                 0x20
#define BIT_ACCEL_FIFO_EN               0x10
#define BITS_GYRO_FIFO_EN               0x0E
#define REG_FIFO_RST            (BANK_0 | 0x68)
#define REG_FIFO_COUNT_H        (BANK_0 | 0x70)
#define REG_FIFO_COUNT_L        (BANK_0 | 0x71)
#define REG_FIFO_R_W            (BANK_0 | 0x72)
#define REG_HW_FIX_DISABLE      (BANK_0 | 0x75)
#define REG_FIFO_CFG            (BANK_0 | 0x76)
#define BIT_MULTI_FIFO_CFG              0x01
#define BIT_SINGLE_FIFO_CFG             0x00
#define REG_ACCEL_XOUT_H_SH     (BANK_0 | 0x2D)
#define REG_ACCEL_XOUT_L_SH     (BANK_0 | 0x2E)
#define REG_ACCEL_YOUT_H_SH     (BANK_0 | 0x2F)
#define REG_ACCEL_YOUT_L_SH     (BANK_0 | 0x30)
#define REG_ACCEL_ZOUT_H_SH     (BANK_0 | 0x31)
#define REG_ACCEL_ZOUT_L_SH     (BANK_0 | 0x32)
#define REG_MEM_START_ADDR      (BANK_0 | 0x7C)
#define REG_MEM_R_W             (BANK_0 | 0x7D)
#define REG_MEM_BANK_SEL        (BANK_0 | 0x7E)
#define REG_TIMEBASE_CORRECTION_PLL   (BANK_1 | 0x28)
#define REG_TIMEBASE_CORRECTION_RCOSC (BANK_1 | 0x29)
#define REG_SELF_TEST1                (BANK_1 | 0x02)
#define REG_SELF_TEST2                (BANK_1 | 0x03)
#define REG_SELF_TEST3                (BANK_1 | 0x04)
#define REG_SELF_TEST4                (BANK_1 | 0x0E)
#define REG_SELF_TEST5                (BANK_1 | 0x0F)
#define REG_SELF_TEST6                (BANK_1 | 0x10)
#define REG_GYRO_SMPLRT_DIV     (BANK_2 | 0x00)
#define REG_GYRO_CONFIG_1       (BANK_2 | 0x01)
#define SHIFT_GYRO_FS_SEL               1
#define SHIFT_GYRO_DLPCFG               3
#define REG_GYRO_CONFIG_2       (BANK_2 | 0x02)
#define BIT_GYRO_CTEN                   0x38
#define REG_ACCEL_SMPLRT_DIV_1  (BANK_2 | 0x10)
#define REG_ACCEL_SMPLRT_DIV_2  (BANK_2 | 0x11)
#define REG_ACCEL_CONFIG        (BANK_2 | 0x14)
#define SHIFT_ACCEL_FS                  1
#define REG_ACCEL_CONFIG_2      (BANK_2 | 0x15)
#define BIT_ACCEL_CTEN                  0x1C
#define REG_PRS_ODR_CONFIG      (BANK_2 | 0x20)
#define REG_PRGM_START_ADDRH    (BANK_2 | 0x50)
#define REG_MOD_CTRL_USR        (BANK_2 | 0x54)
#define BIT_ODR_SYNC                    0x7
#define REG_I2C_MST_ODR_CONFIG  (BANK_3 | 0x0)
#define REG_I2C_MST_CTRL        (BANK_3 | 0x01)
#define BIT_I2C_MST_P_NSR               0x10
#define REG_I2C_MST_DELAY_CTRL  (BANK_3 | 0x02)
#define BIT_SLV0_DLY_EN                 0x01
#define BIT_SLV1_DLY_EN                 0x02
#define BIT_SLV2_DLY_EN                 0x04
#define BIT_SLV3_DLY_EN                 0x08
#define REG_I2C_SLV0_ADDR       (BANK_3 | 0x03)
#define REG_I2C_SLV0_REG        (BANK_3 | 0x04)
#define REG_I2C_SLV0_CTRL       (BANK_3 | 0x05)
#define REG_I2C_SLV0_DO         (BANK_3 | 0x06)
#define REG_I2C_SLV1_ADDR       (BANK_3 | 0x07)
#define REG_I2C_SLV1_REG        (BANK_3 | 0x08)
#define REG_I2C_SLV1_CTRL       (BANK_3 | 0x09)
#define REG_I2C_SLV1_DO         (BANK_3 | 0x0A)
#define REG_I2C_SLV2_ADDR       (BANK_3 | 0x0B)
#define REG_I2C_SLV2_REG        (BANK_3 | 0x0C)
#define REG_I2C_SLV2_CTRL       (BANK_3 | 0x0D)
#define REG_I2C_SLV2_DO         (BANK_3 | 0x0E)
#define REG_I2C_SLV3_ADDR       (BANK_3 | 0x0F)
#define REG_I2C_SLV3_REG        (BANK_3 | 0x10)
#define REG_I2C_SLV3_CTRL       (BANK_3 | 0x11)
#define REG_I2C_SLV3_DO         (BANK_3 | 0x12)
#define REG_I2C_SLV4_CTRL       (BANK_3 | 0x15)
#define INV_MPU_BIT_SLV_EN      0x80
#define INV_MPU_BIT_BYTE_SW     0x40
#define INV_MPU_BIT_REG_DIS     0x20
#define INV_MPU_BIT_GRP         0x10
#define INV_MPU_BIT_I2C_READ    0x80
#define REG_BANK_SEL            0x7F
#define BYTES_PER_SENSOR         6
#define FIFO_COUNT_BYTE          2
#define HARDWARE_FIFO_SIZE       1024
#define FIFO_SIZE                (HARDWARE_FIFO_SIZE * 7 / 8)
#define POWER_UP_TIME            100
#define REG_UP_TIME_USEC         100
#define DMP_RESET_TIME           20
#define GYRO_ENGINE_UP_TIME      50
#define MPU_MEM_BANK_SIZE        256
#define IIO_BUFFER_BYTES         8
#define HEADERED_NORMAL_BYTES    8
#define HEADERED_Q_BYTES         16
#define LEFT_OVER_BYTES          128
#define BASE_SAMPLE_RATE         1125
#ifdef FREQ_225
#define MPU_DEFAULT_DMP_FREQ     225
#define PEDOMETER_FREQ           (MPU_DEFAULT_DMP_FREQ >> 2)
#define DEFAULT_ACCEL_GAIN       (33554432L * 5 / 11)
#else
#define MPU_DEFAULT_DMP_FREQ     102
#define PEDOMETER_FREQ           (MPU_DEFAULT_DMP_FREQ >> 1)
#define DEFAULT_ACCEL_GAIN       33554432L
#endif
#define PED_ACCEL_GAIN           67108864L
#define ALPHA_FILL_PED           858993459
#define A_FILL_PED               214748365
#define MIN_MST_ODR_CONFIG       4
#define THREE_AXES               3
#define NINE_ELEM                (THREE_AXES * THREE_AXES)
#define MPU_TEMP_SHIFT           16
#define SOFT_IRON_MATRIX_SIZE    (4 * 9)
#define DMP_DIVIDER              (BASE_SAMPLE_RATE / MPU_DEFAULT_DMP_FREQ)
#define MAX_5_BIT_VALUE          0x1F
#define BAD_COMPASS_DATA         0x7FFF
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

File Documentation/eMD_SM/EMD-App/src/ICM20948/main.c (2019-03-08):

/*
* ________________________________________________________________________________________________________
* Copyright (c) 2017 InvenSense Inc. All rights reserved.
*
* This software, related documentation and any modifications thereto (collectively “Software”) is subject
* to InvenSense and its licensors' intellectual property rights under U.S. and international copyright
* and other intellectual property rights laws.
*
* InvenSense and its licensors retain all intellectual property and proprietary rights in and to the Software
* and any use, reproduction, disclosure or distribution of the Software without an express license agreement
* from InvenSense is strictly prohibited.
*
* EXCEPT AS OTHERWISE PROVIDED IN A LICENSE AGREEMENT BETWEEN THE PARTIES, THE SOFTWARE IS
* PROVIDED "AS IS", WITHOUT WARRANTY OF ANY KIND, EXPRESS OR IMPLIED, INCLUDING BUT NOT LIMITED
* TO THE WARRANTIES OF MERCHANTABILITY, FITNESS FOR A PARTICULAR PURPOSE AND NON-INFRINGEMENT.
* EXCEPT AS OTHERWISE PROVIDED IN A LICENSE AGREEMENT BETWEEN THE PARTIES, IN NO EVENT SHALL
* INVENSENSE BE LIABLE FOR ANY DIRECT, SPECIAL, INDIRECT, INCIDENTAL, OR CONSEQUENTIAL DAMAGES, OR ANY
* DAMAGES WHATSOEVER RESULTING FROM LOSS OF USE, DATA OR PROFITS, WHETHER IN AN ACTION OF CONTRACT,
* NEGLIGENCE OR OTHER TORTIOUS ACTION, ARISING OUT OF OR IN CONNECTION WITH THE USE OR PERFORMANCE
* OF THE SOFTWARE.
* ________________________________________________________________________________________________________
*/
#include <asf.h>

/* InvenSense drivers and utils */
#include "Invn/Devices/Drivers/Icm20948/Icm20948.h"
#include "Invn/Devices/Drivers/Ak0991x/Ak0991x.h"
#include "Invn/Devices/SensorTypes.h"
#include "Invn/Devices/SensorConfig.h"
#include "Invn/EmbUtils/InvScheduler.h"
#include "Invn/EmbUtils/RingByteBuffer.h"
#include "Invn/EmbUtils/Message.h"
#include "Invn/EmbUtils/ErrorHelper.h"
#include "Invn/EmbUtils/DataConverter.h"
#include "Invn/EmbUtils/RingBuffer.h"
#include "Invn/DynamicProtocol/DynProtocol.h"
#include "Invn/DynamicProtocol/DynProtocolTransportUart.h"

#include "ASF/sam/drivers/pio/pio.h"
#include "ASF/sam/drivers/pio/pio_handler.h"
#include "ASF/sam/drivers/twi/twi.h"
#include "ASF/sam/drivers/tc/tc.h"

#include "main.h"
#include "system.h"
#include "sensor.h"
#include "fw_version.h"

/* Flag set from device irq handler */
volatile int irq_from_device = 0;

static InvSchedulerTask blinkerLedTask;
static InvSchedulerTask commandHandlerTask;

#ifdef INV_MSG_ENABLE
static void msg_printer(int level, const char * str, va_list ap);
#endif

/*
* BlinkerLedTaskMain - Task that blinks the LED.
*/
static void BlinkerLedTaskMain(void * arg){
	(void)arg;

	ioport_toggle_pin_level(LED_0_PIN);
}

uint64_t inv_icm20948_get_time_us(void){
	return InvEMDFrontEnd_getTimestampUs();
}

/*
* CommandHandlerTaskMain - Task that monitors the UART
*/
static void CommandHandlerTaskMain(void * arg){
	(void)arg;

	int byte;
	do {
		byte = EOF;
		__disable_irq();

		if(!RingByteBuffer_isEmpty(&uart_rx_rb)) {
			byte = RingByteBuffer_popByte(&uart_rx_rb);
		}
		__enable_irq();

		if(byte != EOF) {
			DynProTransportUart_rxProcessByte(&transport, (uint8_t)byte);
		}
	} while(byte != EOF);
}

int main (void){

	int rc = 0;

	/* Hardware initialization */
	sysclk_init();
	board_init();
	sysclk_enable_peripheral_clock(ID_TC0);

	/* Configure Device - Host Interface */
	configure_console();

#ifdef INV_MSG_ENABLE
	/* Setup message logging */
	INV_MSG_SETUP(INV_MSG_ENABLE, msg_printer);
#endif

	INV_MSG(INV_MSG_LEVEL_INFO, "###################################");
	INV_MSG(INV_MSG_LEVEL_INFO, "#   ICM20948 example              #");
	INV_MSG(INV_MSG_LEVEL_INFO, "###################################");

	/* Initialize External Sensor Interrupt */
	ext_int_initialize(&ext_interrupt_handler);
	interface_initialize();

	/* Configure sysTick Timer */
	SysTick_Config(sysclk_get_cpu_hz() / MILLISECONDS_PER_SECOND);

	/*
	* Initialize icm20948 serif structure
	*/
	struct inv_icm20948_serif icm20948_serif;
	icm20948_serif.context   = 0; /* no need */
	icm20948_serif.read_reg  = idd_io_hal_read_reg;
	icm20948_serif.write_reg = idd_io_hal_write_reg;
	icm20948_serif.max_read  = 1024*16; /* maximum number of bytes allowed per serial read */
	icm20948_serif.max_write = 1024*16; /* maximum number of bytes allowed per serial write */

	icm20948_serif.is_spi = interface_is_SPI();

	/*
	* Reset icm20948 driver states
	*/
	inv_icm20948_reset_states(&icm_device, &icm20948_serif);

	inv_icm20948_register_aux_compass(&icm_device, INV_ICM20948_COMPASS_ID_AK09916, AK0991x_DEFAULT_I2C_ADDR);

	/*
	* Setup the icm20948 device
	*/
	rc = icm20948_sensor_setup();

	/*
	* Now that Icm20948 device was initialized, we can proceed with DMP image loading
	* This step is mandatory as DMP image are not store in non volatile memory
	*/
	rc += load_dmp3();
	check_rc(rc, "Error sensor_setup/DMP loading.");

	/*
	* Initialize Dynamic protocol stuff
	*/
	DynProTransportUart_init(&transport, iddwrapper_transport_event_cb, 0);
	DynProtocol_init(&protocol, iddwrapper_protocol_event_cb, 0);

	InvScheduler_init(&scheduler);
	InvScheduler_initTask(&scheduler, &commandHandlerTask, "commandHandlerTask", CommandHandlerTaskMain, 0, INVSCHEDULER_TASK_PRIO_MIN, 1);
	InvScheduler_initTask(&scheduler, &blinkerLedTask, "blinkerLedTask", BlinkerLedTaskMain, 0, INVSCHEDULER_TASK_PRIO_MIN+1, 1000000/SCHEDULER_PERIOD);
	InvScheduler_startTask(&blinkerLedTask, 0);
	InvScheduler_startTask(&commandHandlerTask, 0);

	hw_timer_start(20);		// Start the timestamp timer at 20 Hz.
	while (1) {
		InvScheduler_dispatchTasks(&scheduler);

		if (irq_from_device == 1) {
			inv_icm20948_poll_sensor(&icm_device, (void *)0, build_sensor_event_data);

			__disable_irq();
			irq_from_device = 0;
			__enable_irq();
		}
	}

	return 0;
}

#ifdef INV_MSG_ENABLE
/*
* Printer function for message facility
*/
static void msg_printer(int level, const char * str, va_list ap){

	static char out_str[256]; /* static to limit stack usage */
	unsigned idx = 0;
	const char * ptr = out_str;
	const char * s[INV_MSG_LEVEL_MAX] = {
		"",    // INV_MSG_LEVEL_OFF
		"[E] ", // INV_MSG_LEVEL_ERROR
		"[W] ", // INV_MSG_LEVEL_WARNING
		"[I] ", // INV_MSG_LEVEL_INFO
		"[V] ", // INV_MSG_LEVEL_VERBOSE
		"[D] ", // INV_MSG_LEVEL_DEBUG
	};
	idx += snprintf(&out_str[idx], sizeof(out_str) - idx, "%s", s[level]);
	if(idx >= (sizeof(out_str)))
		return;
	idx += vsnprintf(&out_str[idx], sizeof(out_str) - idx, str, ap);
	if(idx >= (sizeof(out_str)))
		return;
	idx += snprintf(&out_str[idx], sizeof(out_str) - idx, "\r\n");
	if(idx >= (sizeof(out_str)))
		return;

	while(*ptr != '\0') {
		usart_serial_putchar(DEBUG_UART, *ptr);
		++ptr;
	}
}
#endif

void InvEMDFrontEnd_busyWaitUsHook(uint32_t us){
	delay_us(us);
}

int InvEMDFrontEnd_isHwFlowCtrlSupportedHook(void){
	return 0;
}

int InvEMDFrontEnd_putcharHook(int c){
	if(usart_serial_putchar(CONF_UART, (uint8_t)c))
		return c;
	else
		return -1;
}

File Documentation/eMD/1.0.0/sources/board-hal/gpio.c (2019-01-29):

/*
 * ________________________________________________________________________________________________________
 * Copyright (c) 2016-2016 InvenSense Inc. All rights reserved.
 *
 * This software, related documentation and any modifications thereto (collectively “Software”) is subject
 * to InvenSense and its licensors' intellectual property rights under U.S. and international copyright
 * and other intellectual property rights laws.
 *
 * InvenSense and its licensors retain all intellectual property and proprietary rights in and to the Software
 * and any use, reproduction, disclosure or distribution of the Software without an express license agreement
 * from InvenSense is strictly prohibited.
 *
 * EXCEPT AS OTHERWISE PROVIDED IN A LICENSE AGREEMENT BETWEEN THE PARTIES, THE SOFTWARE IS
 * PROVIDED "AS IS", WITHOUT WARRANTY OF ANY KIND, EXPRESS OR IMPLIED, INCLUDING BUT NOT LIMITED
 * TO THE WARRANTIES OF MERCHANTABILITY, FITNESS FOR A PARTICULAR PURPOSE AND NON-INFRINGEMENT.
 * EXCEPT AS OTHERWISE PROVIDED IN A LICENSE AGREEMENT BETWEEN THE PARTIES, IN NO EVENT SHALL
 * INVENSENSE BE LIABLE FOR ANY DIRECT, SPECIAL, INDIRECT, INCIDENTAL, OR CONSEQUENTIAL DAMAGES, OR ANY
 * DAMAGES WHATSOEVER RESULTING FROM LOSS OF USE, DATA OR PROFITS, WHETHER IN AN ACTION OF CONTRACT,
 * NEGLIGENCE OR OTHER TORTIOUS ACTION, ARISING OUT OF OR IN CONNECTION WITH THE USE OR PERFORMANCE
 * OF THE SOFTWARE.
 * ________________________________________________________________________________________________________
 */

#include "gpio.h"
#include "nvic_config.h"

// system drivers
#include "stm32f4xx.h"
#include "stm32f4xx_gpio.h"
#include "stm32f4xx_exti.h"
#include "stm32f4xx_syscfg.h"

/** SPI Slave GPIOs **/

#define SPI_SLAVE_GPIO               GPIOB
#define SPI_SLAVE_GPIO_CLK           RCC_AHB1Periph_GPIOB
#define SPI_SLAVE_CS_PIN             GPIO_Pin_12

/** Sensor IRQ GPIOs **/

#define SENSOR_IRQ_D7_GPIO             GPIOA
#define SENSOR_IRQ_D7_GPIO_CLK         RCC_AHB1Periph_GPIOA
#define SENSOR_IRQ_D7_PIN              GPIO_Pin_8

#define SENSOR_IRQ_D6_GPIO             GPIOB
#define SENSOR_IRQ_D6_GPIO_CLK         RCC_AHB1Periph_GPIOB
#define SENSOR_IRQ_D6_PIN              GPIO_Pin_10

#define SENSOR_IRQ_D5_GPIO             GPIOB
#define SENSOR_IRQ_D5_GPIO_CLK         RCC_AHB1Periph_GPIOB
#define SENSOR_IRQ_D5_PIN              GPIO_Pin_4

#define SENSOR_IRQ_D4_GPIO             GPIOB
#define SENSOR_IRQ_D4_GPIO_CLK         RCC_AHB1Periph_GPIOB
#define SENSOR_IRQ_D4_PIN              GPIO_Pin_5

/*
 * Callback for End of frame transfer interruption
 */
static void (*sEnd_of_frame_cb)(void);

/*
 * Callback for GPIO interruption
 */
static void (*sInterrupt_cb)(void * context, int int_num);

/*
 * Context for GPIO interruption callback
 */
static void *sContext;

void gpio_init_pin_out(unsigned pin_num)
{
	GPIO_InitTypeDef   GPIO_InitStructure;

	GPIO_InitStructure.GPIO_Speed   = GPIO_Speed_100MHz;
	GPIO_InitStructure.GPIO_OType 	= GPIO_OType_PP;
	GPIO_InitStructure.GPIO_PuPd 	= GPIO_PuPd_NOPULL;

	if (pin_num == GPIO_PA9) {
		RCC_AHB1PeriphClockCmd(RCC_AHB1Periph_GPIOA, ENABLE);

		/* Init PA.9 as alternate function */
		GPIO_InitStructure.GPIO_Pin     = GPIO_Pin_9;
		GPIO_InitStructure.GPIO_Mode    = GPIO_Mode_OUT;
		GPIO_Init(GPIOA, &GPIO_InitStructure);
		/* reset GPIO PA.9 */
		GPIOA->BSRRH = GPIO_Pin_9;

	} else if (pin_num == GPIO_PB3) {
		RCC_AHB1PeriphClockCmd(RCC_AHB1Periph_GPIOB, ENABLE);

		/* Init PB.3 as output */
		GPIO_InitStructure.GPIO_Pin     = GPIO_Pin_3;
		GPIO_InitStructure.GPIO_Mode    = GPIO_Mode_OUT;
		GPIO_Init(GPIOB, &GPIO_InitStructure);
		/* reset GPIO PB.3 */
		GPIOB->BSRRH = GPIO_Pin_3;
	}
}


int gpio_get_state(unsigned enable_mask)
{
	if(enable_mask & TO_MASK(GPIO_SENSOR_IRQ_D7)) {
		return GPIO_ReadInputDataBit(SENSOR_IRQ_D7_GPIO, SENSOR_IRQ_D7_PIN);
	}
	if(enable_mask & TO_MASK(GPIO_SENSOR_IRQ_D6)) {
		return GPIO_ReadInputDataBit(SENSOR_IRQ_D6_GPIO, SENSOR_IRQ_D6_PIN);
	}
	if(enable_mask & TO_MASK(GPIO_SENSOR_IRQ_D5)) {
		return GPIO_ReadInputDataBit(SENSOR_IRQ_D5_GPIO, SENSOR_IRQ_D5_PIN);
	}
	if(enable_mask & TO_MASK(GPIO_SENSOR_IRQ_D4)) {
		return GPIO_ReadInputDataBit(SENSOR_IRQ_D4_GPIO, SENSOR_IRQ_D4_PIN);
	}
	return -1;
}
void gpio_toggle_pin(unsigned pin_num)
{
	/* <pin_num> comes from enum so it needs translation to GPIO address */
	if(pin_num == GPIO_PB3)
		GPIOB->ODR ^= GPIO_Pin_3;
	else if(pin_num == GPIO_PA9)
		GPIOA->ODR ^= GPIO_Pin_9;
}
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

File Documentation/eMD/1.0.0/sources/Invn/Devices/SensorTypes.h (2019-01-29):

/*
 * ________________________________________________________________________________________________________
 * Copyright (c) 2015-2015 InvenSense Inc. All rights reserved.
 *
 * This software, related documentation and any modifications thereto (collectively “Software”) is subject
 * to InvenSense and its licensors' intellectual property rights under U.S. and international copyright
 * and other intellectual property rights laws.
 *
 * InvenSense and its licensors retain all intellectual property and proprietary rights in and to the Software
 * and any use, reproduction, disclosure or distribution of the Software without an express license agreement
 * from InvenSense is strictly prohibited.
 *
 * EXCEPT AS OTHERWISE PROVIDED IN A LICENSE AGREEMENT BETWEEN THE PARTIES, THE SOFTWARE IS
 * PROVIDED "AS IS", WITHOUT WARRANTY OF ANY KIND, EXPRESS OR IMPLIED, INCLUDING BUT NOT LIMITED
 * TO THE WARRANTIES OF MERCHANTABILITY, FITNESS FOR A PARTICULAR PURPOSE AND NON-INFRINGEMENT.
 * EXCEPT AS OTHERWISE PROVIDED IN A LICENSE AGREEMENT BETWEEN THE PARTIES, IN NO EVENT SHALL
 * INVENSENSE BE LIABLE FOR ANY DIRECT, SPECIAL, INDIRECT, INCIDENTAL, OR CONSEQUENTIAL DAMAGES, OR ANY
 * DAMAGES WHATSOEVER RESULTING FROM LOSS OF USE, DATA OR PROFITS, WHETHER IN AN ACTION OF CONTRACT,
 * NEGLIGENCE OR OTHER TORTIOUS ACTION, ARISING OUT OF OR IN CONNECTION WITH THE USE OR PERFORMANCE
 * OF THE SOFTWARE.
 * ________________________________________________________________________________________________________
 */

/** @defgroup SensorTypes Sensor types
 *  @brief    Sensor related types definitions
 *  @ingroup  Drivers
 *  @{
 */

#ifndef _INV_SENSOR_TYPES_H_
#define _INV_SENSOR_TYPES_H_

#include "Invn/InvExport.h"

#ifdef __cplusplus
extern "C" {
#endif

#include <stdint.h>
#include "Invn/InvBool.h"

/** @brief Sensor type identifier definition
 */
enum inv_sensor_type {
	INV_SENSOR_TYPE_RESERVED                     = 0 ,  /**< Reserved ID: do not use */
	INV_SENSOR_TYPE_ACCELEROMETER                = 1 ,  /**< Accelerometer */
	INV_SENSOR_TYPE_MAGNETOMETER                 = 2 ,  /**< Magnetic field */
	INV_SENSOR_TYPE_ORIENTATION                  = 3 ,  /**< Deprecated orientation */
	INV_SENSOR_TYPE_GYROSCOPE                    = 4 ,  /**< Gyroscope */
	INV_SENSOR_TYPE_LIGHT                        = 5 ,  /**< Ambient light sensor */
	INV_SENSOR_TYPE_PRESSURE                     = 6 ,  /**< Barometer */
	INV_SENSOR_TYPE_TEMPERATURE                  = 7 ,  /**< Temperature */
	INV_SENSOR_TYPE_PROXIMITY                    = 8 ,  /**< Proximity */
	INV_SENSOR_TYPE_GRAVITY                      = 9 ,  /**< Gravity */
	INV_SENSOR_TYPE_LINEAR_ACCELERATION          = 10,  /**< Linear acceleration */
	INV_SENSOR_TYPE_ROTATION_VECTOR              = 11,  /**< Rotation vector */
	INV_SENSOR_TYPE_HUMIDITY                     = 12,  /**< Relative humidity */
	INV_SENSOR_TYPE_AMBIENT_TEMPERATURE          = 13,  /**< Ambient temperature */
	INV_SENSOR_TYPE_UNCAL_MAGNETOMETER           = 14,  /**< Uncalibrated magnetic field */
	INV_SENSOR_TYPE_GAME_ROTATION_VECTOR         = 15,  /**< Game rotation vector */
	INV_SENSOR_TYPE_UNCAL_GYROSCOPE              = 16,  /**< Uncalibrated gyroscope */
	INV_SENSOR_TYPE_SMD                          = 17,  /**< Significant motion detection */
	INV_SENSOR_TYPE_STEP_DETECTOR                = 18,  /**< Step detector */
	INV_SENSOR_TYPE_STEP_COUNTER                 = 19,  /**< Step counter */
	INV_SENSOR_TYPE_GEOMAG_ROTATION_VECTOR       = 20,  /**< Geomagnetic rotation vector */
	INV_SENSOR_TYPE_HEART_RATE                   = 21,  /**< Heart rate */
	INV_SENSOR_TYPE_TILT_DETECTOR                = 22,  /**< Tilt detector */
	INV_SENSOR_TYPE_WAKE_GESTURE                 = 23,  /**< Wake-up gesture  */
	INV_SENSOR_TYPE_GLANCE_GESTURE               = 24,  /**< Glance gesture  */
	INV_SENSOR_TYPE_PICK_UP_GESTURE              = 25,  /**< Pick-up gesture */
	INV_SENSOR_TYPE_BAC                          = 26,  /**< Basic Activity Classifier */
	INV_SENSOR_TYPE_PDR                          = 27,  /**< Pedestrian Dead Reckoning */
	INV_SENSOR_TYPE_B2S                          = 28,  /**< Bring to see */
	INV_SENSOR_TYPE_3AXIS                        = 29,  /**< 3 Axis sensor */
	INV_SENSOR_TYPE_EIS                          = 30,  /**< Electronic Image Stabilization */
	INV_SENSOR_TYPE_OIS                          = 31,  /**< Optical Image Stabilization */
	INV_SENSOR_TYPE_RAW_ACCELEROMETER            = 32,  /**< Raw accelerometer */
	INV_SENSOR_TYPE_RAW_GYROSCOPE                = 33,  /**< Raw gyroscope */
	INV_SENSOR_TYPE_RAW_MAGNETOMETER             = 34,  /**< Raw magnetometer */
	INV_SENSOR_TYPE_RAW_TEMPERATURE              = 35,  /**< Raw temperature */
	INV_SENSOR_TYPE_CUSTOM_PRESSURE              = 36,  /**< Custom Pressure Sensor */
	INV_SENSOR_TYPE_MIC                          = 37,  /**< Stream audio from microphone */
	INV_SENSOR_TYPE_TSIMU                        = 38,  /**< TS-IMU */
	INV_SENSOR_TYPE_RAW_PPG                      = 39,  /**< Raw Photoplethysmogram */
	INV_SENSOR_TYPE_HRV                          = 40,  /**< Heart rate variability */
	INV_SENSOR_TYPE_SLEEP_ANALYSIS               = 41,  /**< Sleep analysis */
	INV_SENSOR_TYPE_BAC_EXTENDED                 = 42,  /**< Basic Activity Classifier Extended */
	INV_SENSOR_TYPE_BAC_STATISTICS               = 43,  /**< Basic Activity Classifier Statistics */
	INV_SENSOR_TYPE_FLOOR_CLIMB_COUNTER          = 44,  /**< Floor Climbed Counter */
	INV_SENSOR_TYPE_ENERGY_EXPENDITURE           = 45,  /**< Energy Expenditure */
	INV_SENSOR_TYPE_DISTANCE                     = 46,  /**< Distance */
	INV_SENSOR_TYPE_SHAKE                        = 47,  /**< Shake Gesture */
	INV_SENSOR_TYPE_DOUBLE_TAP                   = 48,  /**< Double Tap */
	INV_SENSOR_TYPE_CUSTOM0,                            /**< Custom sensor ID 0 */
	INV_SENSOR_TYPE_CUSTOM1,                            /**< Custom sensor ID 1 */
	INV_SENSOR_TYPE_CUSTOM2,                            /**< Custom sensor ID 2 */
	INV_SENSOR_TYPE_CUSTOM3,                            /**< Custom sensor ID 3 */
	INV_SENSOR_TYPE_CUSTOM4,                            /**< Custom sensor ID 4 */
	INV_SENSOR_TYPE_CUSTOM5,                            /**< Custom sensor ID 5 */
	INV_SENSOR_TYPE_CUSTOM6,                            /**< Custom sensor ID 6 */
	INV_SENSOR_TYPE_CUSTOM7,                            /**< Custom sensor ID 7 */
	INV_SENSOR_TYPE_WOM,                                /**< Wake-up on motion */
	INV_SENSOR_TYPE_SEDENTARY_REMIND,                   /**< Sedentary Remind */
	INV_SENSOR_TYPE_DATA_ENCRYPTION,                    /**< Data Encryption */
	INV_SENSOR_TYPE_FSYNC_EVENT,                        /**< FSYNC event */
	INV_SENSOR_TYPE_HIGH_RATE_GYRO,                     /**< High Rate Gyro */
	INV_SENSOR_TYPE_CUSTOM_BSCD,                        /**< Custom BAC StepCounter Calorie counter and Distance counter */
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

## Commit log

2019-01-15 Create schematic and initial board layout
    [SparkFun_IMU_Breakout_ICM-20948.brd, SparkFun_IMU_Breakout_ICM-20948.sch]
2019-01-15 Prettified the schematic
    [SparkFun_IMU_Breakout_ICM-20948.brd, SparkFun_IMU_Breakout_ICM-20948.sch]
2019-01-16 Push to work from laptop
    [Board_Design_Checklist.xls, SparkFun_IMU_Breakout_ICM-20948.brd, SparkFun_IMU_Breakout_ICM-20948.sch]
2019-01-16 95% ready for review commit
    [SparkFun_IMU_Breakout_ICM-20948.brd]
2019-01-16 Design review
    Made all routing look as clean as possible
    [SparkFun_IMU_Breakout_ICM-20948.brd]
2019-01-16 Trace routing changes during design review
    [SparkFun_IMU_Breakout_ICM-20948.brd, SparkFun_IMU_Breakout_ICM-20948.sch]
2019-01-16 Fixes notes from issue #1
    In response to issue #1 I have:
    - Replaced an existing 0.1 uF cap with 1.0 uF
    - Changed address references to hex in .sch
    - Questioned why we worry about vector font now that we use Buzzard
    - Tried LED at 1.8V w and w/o CL resistor (1k). All is well
    - Fixed all silk issues
    - Research indicates that copper is not ferromagnetic (instead it is dimagnetic) so not a concern for the magnetometer
    - Moved triple jumpers away from obstacles
    - Slightly improved ground pour connectivity
    [SparkFun_IMU_Breakout_ICM-20948.brd, SparkFun_IMU_Breakout_ICM-20948.sch]
2019-01-17 Add PWR LED and axes labels
    [Board_Design_Checklist_SparkFun_IMU_Breakout_-_ICM-20948_v10.xls, SparkFun_IMU_Breakout_ICM-20948.brd, SparkFun_IMU_Breakout_ICM-20948.sch]
2019-01-17 Reposition axis labels
    [SparkFun_IMU_Breakout_ICM-20948.brd]
2019-01-18 Fixed items 1-7 of issue #2
    1. Added PCB to BOM, and built in a reminder to the BOM ULP to do the same
    2. Changed the name to "SparkFun 9DoF IMU Breakout - ICM-20948 (Qwiic)" and now the silk name reads "Qwiic 9DoF IMU /n ICM-20948"
    3. Will not flip the board after approving DRC errors
    4. Fixed
    5. Fixed
    6. Done
    7. Adjusted ICM package so as not to overlap
    Waiting on item 8 because it is a drastic change and I want a commit ahead of it to fall back to
    [SparkFun_IMU_Breakout_ICM-20948.brd, SparkFun_IMU_Breakout_ICM-20948.sch]
2019-01-18 Fixed I2C heasder order
    Also adjusted silkcreen labels to reflect the new order
    [SparkFun_IMU_Breakout_ICM-20948.brd, SparkFun_IMU_Breakout_ICM-20948.sch]
2019-01-18 Approved all errors
    [SparkFun_IMU_Breakout_ICM-20948.brd]
2019-01-18 Revert "Approved all errors"
    This reverts commit c58a3cda532a6d6b9316c1cbf57724f808b0484f.
    [SparkFun_IMU_Breakout_ICM-20948.brd]
2019-01-18 Well, I meant to say that I approved all *approvable* errors...
    [SparkFun_IMU_Breakout_ICM-20948.brd]
2019-03-08 Swap TXB0108 for TXS0108 - still needs last check, design review, and finalization
    [SparkFun_IMU_Breakout_ICM-20948.brd, SparkFun_IMU_Breakout_ICM-20948.sch]
2019-03-11 v20
    v20 is intended to fix the I2C communications. We've identified that the TXB0108 logic level translation IC was unable to drive open-drain busses. To address this we've replaced that IC with the TXS0108 - a very similar chip that IS able to drive open-drain busses.
    [Board_Design_Checklist.xls, Board_Design_Checklist_SparkFun_9DOF_IMU_Breakout-ICM-20948_v20.xls, Board_Design_Checklist_SparkFun_IMU_Breakout_-_ICM-20948_v10.x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]
2019-03-14 Post design review changes for v20
    - PWR silk changed to text only
    - Moved P1 indicator on ICM-20948
    - I<sup>2<\sup>C
    - AD0 -> ADR
    - No more '0' label for ADR
    - Vin range double checked
    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
    [SparkFun_IMU_Breakout_ICM-20948.brd, SparkFun_IMU_Breakout_ICM-20948.sch]
2019-03-14 Final checklist review with Eric v20
    [Board_Design_Checklist.xls, Board_Design_Checklist_SparkFun_9DOF_IMU_Breakout-ICM-20948_v20 - Copy.xls, Board_Design_Checklist_SparkFun_9DOF_IMU_Breakout-ICM-2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]
2019-03-14 Reove checklists
    [Board_Design_Checklist.xls, Board_Design_Checklist_SparkFun_9DOF_IMU_Breakout-ICM-20948_v20 - Copy.xls, Board_Design_Checklist_SparkFun_IMU_Breakout_-_ICM-2094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]
2019-04-11 Fix I2C Pullup Issue
    The combination of pullup resistors on the breakout, within the TXS0108, and on the BlackBoard Qwiic Level shifter conspired to make it impossible for the ICM to pull the data line low.
    Fix is to rely on only the internal pullup resistors within the TXS0108.
    Also removed a stray silk item from the board
    [SparkFun_IMU_Breakout_ICM-20948.brd, SparkFun_IMU_Breakout_ICM-20948.sch]
2019-04-11 Made assembly sheet nicer
    [SparkFun_IMU_Breakout_ICM-20948.brd]
2019-04-19 Laid out board for MOSFET trick evaluation (prototype)
    [SparkFun_IMU_Breakout_ICM-20948_FET_EVAL.brd, SparkFun_IMU_Breakout_ICM-20948_FET_EVAL.sch]
2019-04-19 Updated test point package with keepout
    [SparkFun_IMU_Breakout_ICM-20948_FET_EVAL.brd, SparkFun_IMU_Breakout_ICM-20948_FET_EVAL.sch]
2019-04-19 Commit for design review
    [SparkFun_IMU_Breakout_ICM-20948_FET_EVAL.brd]
2019-04-23 Move CC block, ready for proto review
    [SparkFun_IMU_Breakout_ICM-20948_FET_EVAL.brd]
2019-04-23 Changes from design review
    [SparkFun_IMU_Breakout_ICM-20948_FET_EVAL-Panel.GBL, SparkFun_IMU_Breakout_ICM-20948_FET_EVAL-Panel.GBO, SparkFun_IMU_Breakout_ICM-20948_FET_EVAL-Panel.GBS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]
2019-04-23 Better pour
    [SparkFun_IMU_Breakout_ICM-20948_FET_EVAL.brd]
2019-05-09 Laid out v30
    [SparkFun_IMU_Breakout_ICM-20948.brd, SparkFun_IMU_Breakout_ICM-20948.sch, SparkFun_IMU_Breakout_ICM-20948_FET_EVAL.brd]
2019-05-09 Ran board design checklist ahead of the review
    [Board_Design_Checklist.xls, Board_Design_Checklist_SparkFun Qwiic 9DoF IMU - ICM-20948_v30.xls, SparkFun_IMU_Breakout_ICM-20948.brd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]
2019-05-09 Changes from design review
    Level shifter circuit spacing
    Axes indicators
    Routing touch-ups
    LED resistor change
    [SparkFun_IMU_Breakout_ICM-20948.brd, SparkFun_IMU_Breakout_ICM-20948.sch]
2019-05-09 Remove redundant values on MOSFETs
    [SparkFun_IMU_Breakout_ICM-20948.brd, SparkFun_IMU_Breakout_ICM-20948.sch]
2019-05-09 Fix spacing on MOSFET level shifter
    [SparkFun_IMU_Breakout_ICM-20948.brd]
2019-05-20 Fix short circuit
    [SparkFun_IMU_Breakout_ICM-20948.brd]
2019-05-28 Remove FET Eval schematic and board
    [SparkFun_IMU_Breakout_ICM-20948_FET_EVAL-Panel.GBL, SparkFun_IMU_Breakout_ICM-20948_FET_EVAL-Panel.GBO, SparkFun_IMU_Breakout_ICM-20948_FET_EVAL-Panel.GBS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]
2019-05-28 Remove cheklists
    [Board_Design_Checklist.xls, Board_Design_Checklist_SparkFun Qwiic 9DoF IMU - ICM-20948_v30.xls]
2019-06-03 Fix swapped silk for v31
    Silk was mislabeled after changing the order of the "secondary" side headers.
    [SparkFun_IMU_Breakout_ICM-20948.brd, SparkFun_IMU_Breakout_ICM-20948.sch]
2019-06-04 Triple-check changes w/ Eli
    Increased axes label readability, made routing out of mosfets uniform (very small copper changes)
    [SparkFun_IMU_Breakout_ICM-20948.brd]
2019-06-04 ??? Eagle Changes ???
    Only ran the DRC
    [SparkFun_IMU_Breakout_ICM-20948.brd]

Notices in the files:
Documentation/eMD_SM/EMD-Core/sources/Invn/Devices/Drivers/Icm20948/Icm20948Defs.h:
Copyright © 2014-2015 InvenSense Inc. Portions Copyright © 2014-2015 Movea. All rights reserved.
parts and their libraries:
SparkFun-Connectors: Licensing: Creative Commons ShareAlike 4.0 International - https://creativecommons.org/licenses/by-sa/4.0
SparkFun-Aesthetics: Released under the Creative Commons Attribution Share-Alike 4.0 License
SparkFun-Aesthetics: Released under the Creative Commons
